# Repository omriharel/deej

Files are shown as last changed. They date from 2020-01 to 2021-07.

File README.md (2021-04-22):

# deej

deej is an **open-source hardware volume mixer** for Windows and Linux PCs. It lets you use real-life sliders (like a DJ!) to **seamlessly control the volumes of different apps** (such as your music player, the game you're playing and your voice chat session) without having to stop what you're doing.

**Join the [deej Discord server](https://discord.gg/nf88NJu) if you need help or have any questions!**



> **_New:_** [work-in-progress deej FAQ](./docs/faq/faq.md)!

deej consists of a [lightweight desktop client](#features) written in Go, and an Arduino-based hardware setup that's simple and cheap to build. [**Check out some versions built by members of our community!**](./community.md)

**[Download the latest release](https://github.com/omriharel/deej/releases/latest) | [Video demonstration](https://youtu.be/VoByJ4USMr8) | [Build video by Tech Always](https://youtu.be/x2yXbFiiAeI)**

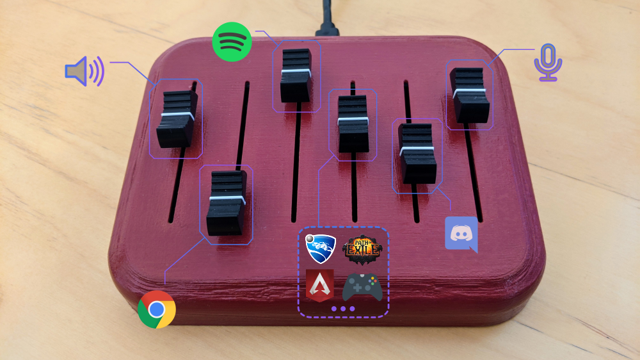
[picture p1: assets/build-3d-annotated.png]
deej


> _**Psst!** [No 3D printer? No problem!](./assets/build-shoebox.jpg)_ You can build deej on some cardboard, a shoebox or even a breadboard :)

## Table of contents

- [Features](#features)
- [How it works](#how-it-works)
  - [Hardware](#hardware)
    - [Schematic](#schematic)
  - [Software](#software)
- [Slider mapping (configuration)](#slider-mapping-configuration)
- [Build your own!](#build-your-own)
  - [FAQ](#faq)
  - [Build video](#build-video)
  - [Bill of Materials](#bill-of-materials)
  - [Thingiverse collection](#thingiverse-collection)
  - [Build procedure](#build-procedure)
- [How to run](#how-to-run)
  - [Requirements](#requirements)
  - [Download and installation](#download-and-installation)
  - [Building from source](#building-from-source)
- [Community](#community)
- [License](#license)

## Features

deej is written in Go and [distributed](https://github.com/omriharel/deej/releases/latest) as a portable (no installer needed) executable.

- Bind apps to different sliders
  - Bind multiple apps per slider (i.e. one slider for all your games)
  - Bind the master channel
  - Bind "system sounds" (on Windows)
  - Bind specific audio devices by name (on Windows)
  - Bind currently active app (on Windows)
  - Bind all other unassigned apps
- Control your microphone's input level
- Lightweight desktop client, consuming around 10MB of memory
- Runs from your system tray
- Helpful notifications to let you know if something isn't working

> **Looking for the older Python version?** It's no longer maintained, but you can always find it in the [`legacy-python` branch](https://github.com/omriharel/deej/tree/legacy-python).

## How it works

### Hardware

- The sliders are connected to 5 (or as many as you like) analog pins on an Arduino Nano/Uno board. They're powered from the board's 5V output (see schematic)
- The board connects via a USB cable to the PC

#### Schematic

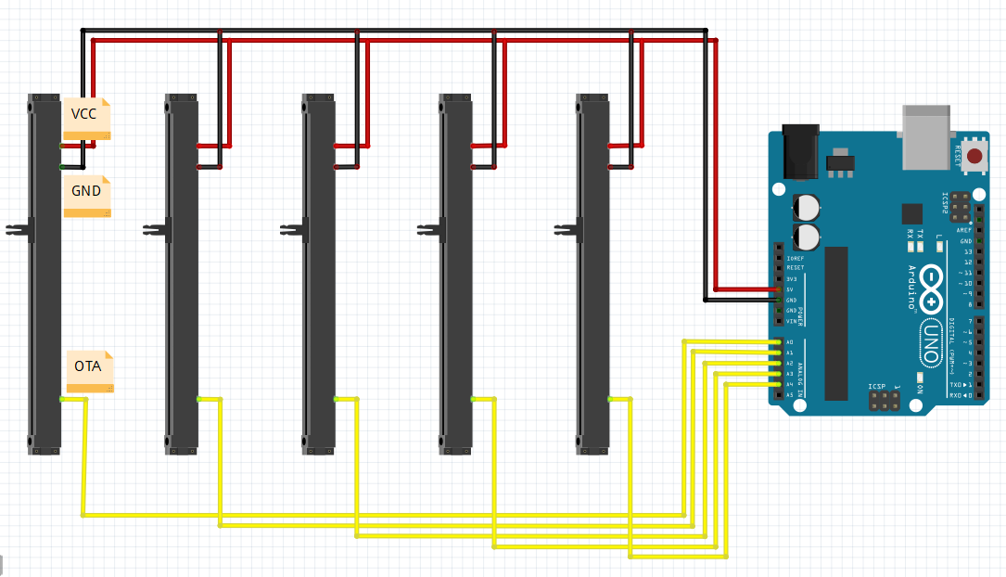
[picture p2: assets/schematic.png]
Hardware schematic


### Software

- The code running on the Arduino board is a [C program](./arduino/deej-5-sliders-vanilla/deej-5-sliders-vanilla.ino) constantly writing current slider values over its serial interface
- The PC runs a lightweight [Go client](./pkg/deej/cmd/main.go) in the background. This client reads the serial stream and adjusts app volumes according to the given configuration file

## Slider mapping (configuration)

deej uses a simple YAML-formatted configuration file named [`config.yaml`](./config.yaml), placed alongside the deej executable.

The config file determines which applications (and devices) are mapped to which sliders, and which parameters to use for the connection to the Arduino board, as well as other user preferences.

**This file auto-reloads when its contents are changed, so you can change application mappings on-the-fly without restarting deej.**

It looks like this:

```yaml
slider_mapping:
  0: master
  1: chrome.exe
  2: spotify.exe
  3:
    - pathofexile_x64.exe
    - rocketleague.exe
  4: discord.exe

# set this to true if you want the controls inverted (i.e. top is 0%, bottom is 100%)
invert_sliders: false

# settings for connecting to the arduino board
com_port: COM4
baud_rate: 9600

# adjust the amount of signal noise reduction depending on your hardware quality
# supported values are "low" (excellent hardware), "default" (regular hardware) or "high" (bad, noisy hardware)
noise_reduction: default
```

- `master` is a special option to control the master volume of the system _(uses the default playback device)_
- `mic` is a special option to control your microphone's input level _(uses the default recording device)_
- `deej.unmapped` is a special option to control all apps that aren't bound to any slider ("everything else")
- On Windows, `deej.current` is a special option to control whichever app is currently in focus
- On Windows, you can specify a device's full name, i.e. `Speakers (Realtek High Definition Audio)`, to bind that device's level to a slider. This doesn't conflict with the default `master` and `mic` options, and works for both input and output devices.
  - Be sure to use the full device name, as seen in the menu that comes up when left-clicking the speaker icon in the tray menu
- `system` is a special option on Windows to control the "System sounds" volume in the Windows mixer
- All names are case-**in**sensitive, meaning both `chrome.exe` and `CHROME.exe` will work
- You can create groups of process names (using a list) to either:
    - control more than one app with a single slider
    - choose whichever process in the group that's currently running (i.e. to have one slider control any game you're playing)

## Build your own!

Building deej is very simple. You only need a few relatively cheap parts - it's an excellent starter project (and my first Arduino project, personally). Remember that if you need any help or have a question that's not answered here, you can always [join the deej Discord server](https://discord.gg/nf88NJu).

Build deej for yourself, or as an awesome gift for your gaming buddies!

### FAQ

I've started a highly focused effort of writing a proper FAQ page for deej, covering many basic and advanced topics.

It is still _very much a work-in-progress_, but I'm happy to [share it in its current state](./docs/faq/faq.md) in hopes that it at least covers some questions you might have.

FAQ feedback in our [community Discord](https://discord.gg/nf88NJu) is strongly encouraged :)

### Build video

In case you prefer watching to reading, Charles from the [**Tech Always**](https://www.youtube.com/c/TechAlways) YouTube channel has made [**a fantastic video**](https://youtu.be/x2yXbFiiAeI) that covers the basics of building deej for yourself, including parts, costs, assembly and software. I highly recommend checking it out!

### Bill of Materials

- An Arduino Nano, Pro Micro or Uno board
  - I officially recommend using a Nano or a Pro Micro for their smaller form-factor, friendlier USB connectors and more analog pins. Plus they're cheaper
  - You can also use any other development board that has a Serial over USB interface
- A few slider potentiometers, up to your number of free analog pins (the cheaper ones cost around 1-2 USD each, and come with a standard 10K Ohm variable resistor. These _should_ work just fine for this project)
  - **Important:** make sure to get **linear** sliders, not logarithmic ones! Check the product description
  - You can also use circular knobs if you like
- Some wires
- Any kind of box to hold everything together. **You don't need a 3D printer for this project!** It works fantastically with just a piece of cardboard or a shoebox. That being said, if you do have one, read on...

### Thingiverse collection

With many different 3D-printed designs being added to our [community showcase](./community.md), it felt right to gather all of them in a Thingiverse collection for you to browse. If you have access to a 3D printer, feel free to use one of the designs in your build.

**[Visit our community-created design collection on Thingiverse!](https://thingiverse.com/omriharel/collections/deej)**

> You can also [submit your own](https://discord.gg/nf88NJu) design to be added to the collection. Regardless, if you do upload your design to Thingiverse, _please add a `deej` tag to it so that others can find it more easily_.

### Build procedure

- Connect everything according to the [schematic](#schematic)
- Test with a multimeter to be sure your sliders are hooked up correctly
- Flash the Arduino chip with the sketch in [`arduino\deej-5-sliders-vanilla`](./arduino/deej-5-sliders-vanilla/deej-5-sliders-vanilla.ino)
  - _Important:_ If you have more or less than 5 sliders, you must edit the sketch to match what you have
- After flashing, check the serial monitor. You should see a constant stream of values separated by a pipe (`|`) character, e.g. `0|240|1023|0|483`
  - When you move a slider, its corresponding value should move between 0 and 1023
- Congratulations, you're now ready to run the deej executable!

## How to run

### Requirements

#### Windows

- Windows. That's it

#### Linux

- Install `libgtk-3-dev`, `libappindicator3-dev` and `libwebkit2gtk-4.0-dev` for system tray support. Pre-built Linux binaries aren't currently released, so you'll need to [build from source](#building-from-source). If there's demand for pre-built binaries, please [let me know](https://discord.gg/nf88NJu)!

### Download and installation

- Head over to the [releases page](https://github.com/omriharel/deej/releases) and download the [latest version](https://github.com/omriharel/deej/releases/latest)'s executable and configuration file (`deej.exe` and `config.yaml`)
- Place them in the same directory anywhere on your machine
- (Optional, on Windows) Create a shortcut to `deej.exe` and copy it to `%APPDATA%\Microsoft\Windows\Start Menu\Programs\Startup` to have deej run on boot

### Building from source

If you'd rather not download a compiled executable, or want to extend deej or modify it to your needs, feel free to clone the repository and build it yourself. All you need is a Go 1.14 (or above) environment on your machine. If you go this route, make sure to check out the [developer scripts](./pkg/deej/scripts).

Like other Go packages, you can also use the `go get` tool: `go get -u github.com/omriharel/deej`. Please note that the package code now resides in the `pkg/deej` directory, and needs to be imported from there if used inside another project.

If you need any help with this, please [join our Discord server](https://discord.gg/nf88NJu).

## Community



deej is a relatively new project, but a vibrant and awesome community is rapidly growing around it. Come hang out with us in the [deej Discord server](https://discord.gg/nf88NJu), or check out a whole bunch of cool and creative builds made by our members in the [community showcase](./community.md).

The server is also a great place to ask questions, suggest features or report bugs (but of course, feel free to use GitHub if you prefer).

### Donations

If you love deej and want to show your support for this project, you can do so using the link below. Please don't feel obligated to donate - building the project and telling your friends about it goes a very long way! Thank you very much.



### Contributing

Please see [`docs/CONTRIBUTING.md`](./docs/CONTRIBUTING.md).

## License

deej is released under the [MIT license](./LICENSE).

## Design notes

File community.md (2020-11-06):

# Community showcase

This is a showcase of `deej` versions built by people around the world. Many of those who featured their builds here regularly hang around in [our Discord server](https://discord.gg/nf88NJu), so you can ask them any questions you might have.

We've also gathered many of the community-created 3D designs featured here in a [Thingiverse collection](https://thingiverse.com/omriharel/collections/deej) for your viewing pleasure. Feel free to use them for your own builds if you have access to a 3D printer.

If you built yourself one of these things, I'd love to [add yours](https://discord.gg/nf88NJu)!

## [/u/Aithorn](https://reddit.com/user/Aithorn)

**Links**: [Imgur album](https://imgur.com/a/Y1rKJmc) | [Reddit](https://redd.it/fc2l3x) | [Enclosure model on Thingiverse](https://www.thingiverse.com/thing:4196719) | [Featured on Arduino Blog!](https://blog.arduino.cc/2020/03/04/control-the-volume-of-programs-running-on-your-windows-pc-like-a-dj/) | [Alternate knobs](https://i.imgur.com/WjaA58d.jpg)

This build features a very neat 3D-printed enclosure to fit the sliders, and uses an Arduino Nano board.

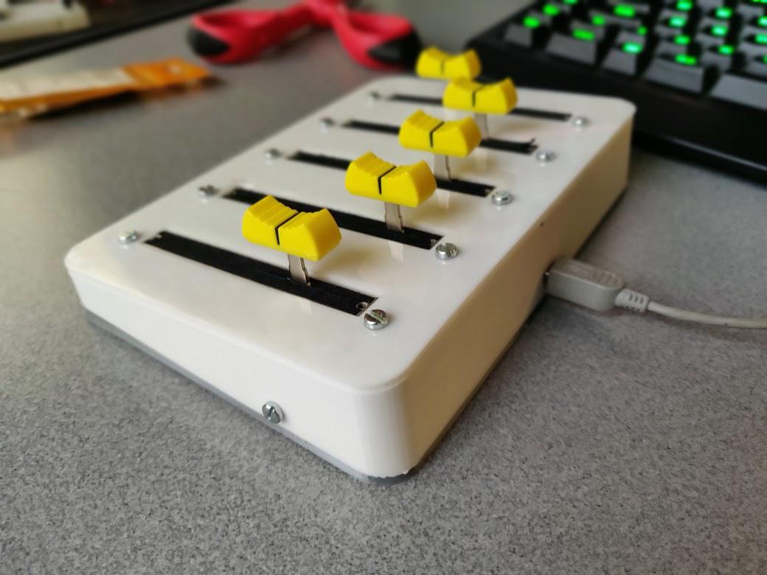
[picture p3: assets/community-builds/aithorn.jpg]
/u/Aithorn


## [Bupher](https://github.com/Bupher)

**Links**: [Imgur album](https://imgur.com/a/5uHYhxW) | [Enclosure model on Thingiverse](https://www.thingiverse.com/thing:4641048) | [GitHub fork](https://github.com/Bupher/deej) | [Video 1](https://youtu.be/O2UJv-sJEjA) | [Video 2](https://youtu.be/psEt-rckr8U)

This updated build uses circular knobs instead of sliders, and adds a 7-segment display showing the volume of the last adjusted knob. The five buttons are used to trigger various macros that the author configured separately. Most recently this build was augmented to include built-in support for Corsair's iCUE RGB control. This allows using Corsair's desktop software to control the lighting on this deej design similarly to an RGB keyboard. The required Arduino-side code modifications are available in Bupher's fork (link above). Very cool!

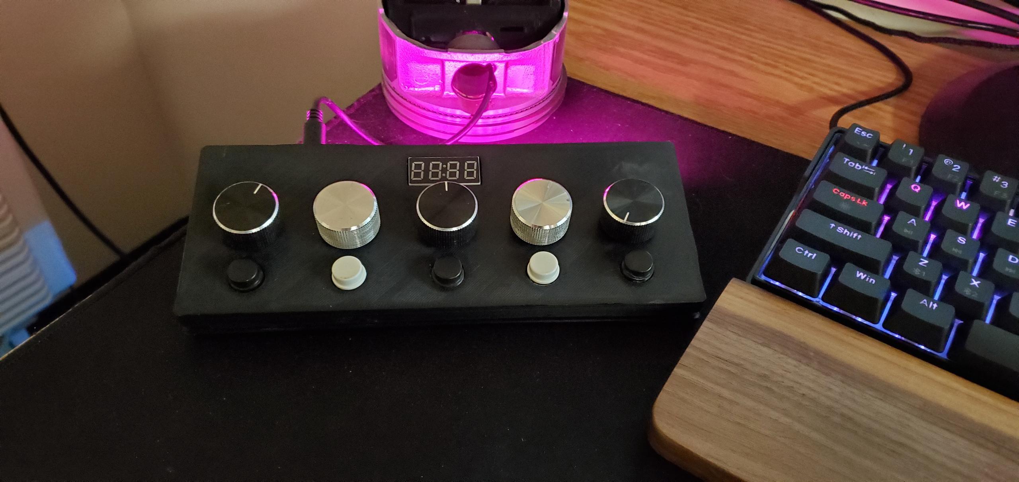
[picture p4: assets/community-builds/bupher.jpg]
Bupher


## Dimitar

**Links**: Schematic ([.png](./assets/community-builds/extra/dimitar-schematic.png) | [.sch](./assets/community-builds/extra/dimitar-schematic.sch))

This build, based on the above 3D-printed enclosure by [/u/Aithorn](#uaithorn), adds onto it with additional holes drilled for fading LEDs and mute toggles. Their wiring is detailed in the schematic that Dimitar has kindly provided (link above).. The sleek dark appearance, coupled with the differently colored knobs and LEDs, makes for a very professional look.

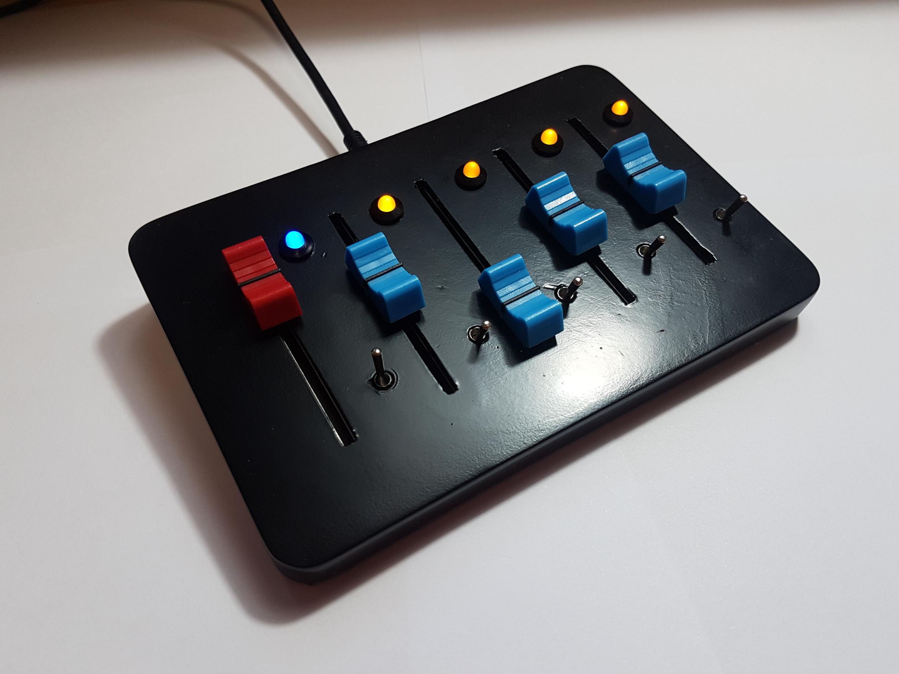
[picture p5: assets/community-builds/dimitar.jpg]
Dimitar


## [/u/jeremytodd1](https://reddit.com/user/jeremytodd1)

**Links**: [Imgur album](https://imgur.com/a/ys1RLwr)

This build is based on the above 3D-printed enclosure by [/u/Aithorn](#uaithorn) and also uses their 3D-printed knobs for its sliders.

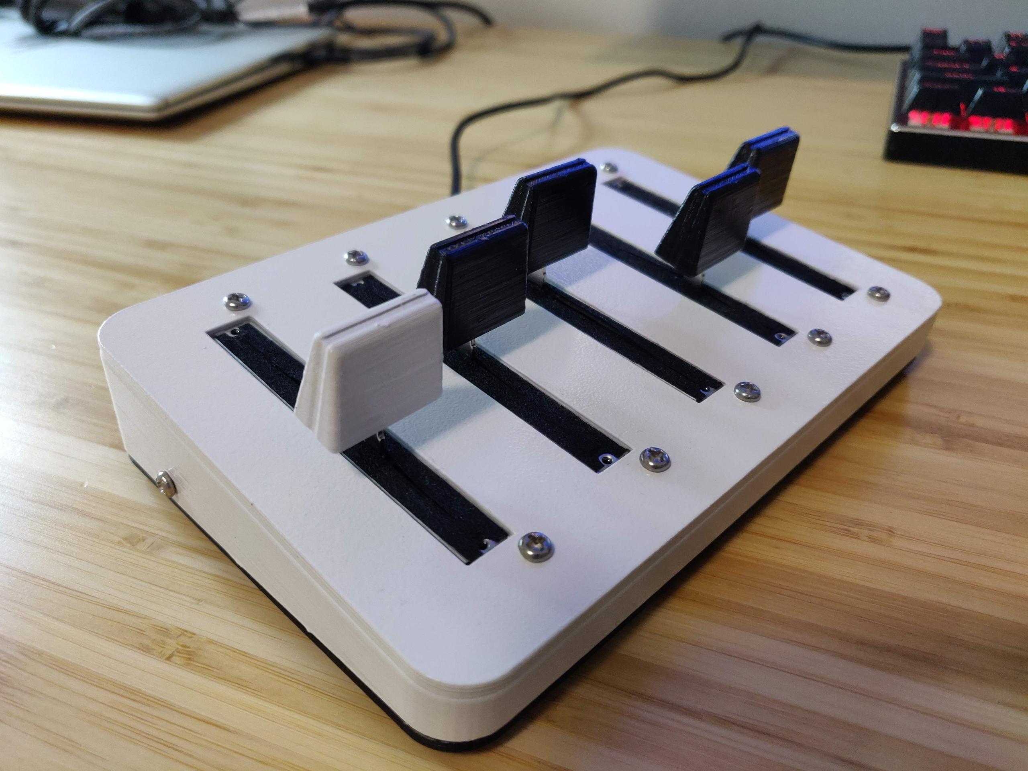
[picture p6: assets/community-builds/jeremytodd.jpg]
/u/jeremytodd1


## CptnObvious

**Links**: [Imgur album](https://imgur.com/a/pnptoo7)

This build uses a flat 3D-printed enclosure, but the real kicker is its magnetically-snapping application logo covers, made with a midway-filament-swapping technique. Looking snappy!

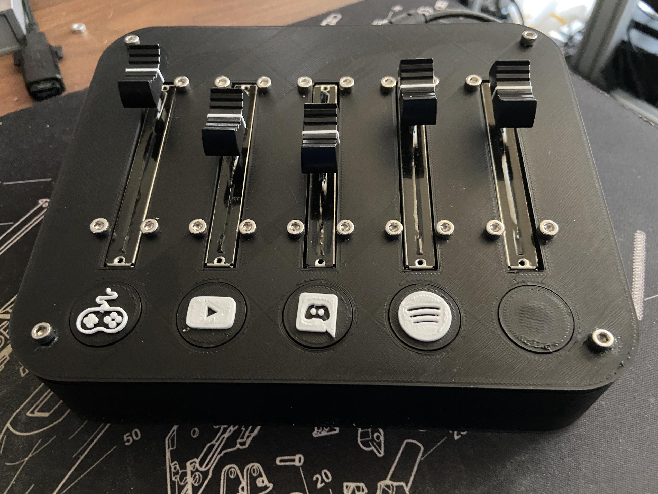
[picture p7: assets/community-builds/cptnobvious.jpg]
CptnObvious


## nightfox939

**Links**: [Imgur album](https://imgur.com/a/rrLbTHI) | [Enclosure model on Thingiverse](https://www.thingiverse.com/thing:4460296)

This build takes a different spin on 3D-printed enclosures by positioning the sliders at an angle, such that the box can be placed right behind the keyboard (as shown [here](https://i.imgur.com/FuvaaTO.jpg)). It also features seven sliders, which is fantastic for power users.

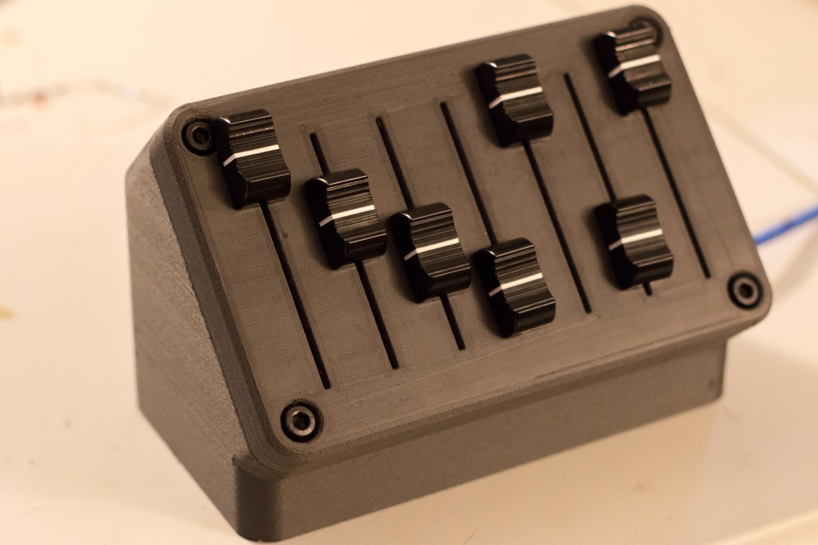
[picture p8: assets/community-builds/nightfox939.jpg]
nightfox939


## [Snackya](https://github.com/Snackya)

**Links**: [Imgur album](https://imgur.com/a/ZL6UBuR) | [GitHub repository with PCB files and instructions](https://github.com/Snackya/Snackboard-mix)

This one's a very special build, as it's designed to look great with absolutely no 3D printing, mill or any casing at all. It's made with custom PCBs that are mounted together with bolts and nuts. The top plate's silkscreen layer adds its own visual flair. The build uses six 100 mm sliders and an Arduino Pro Micro. Snackya has kindly provided the gerber files, as well as detailed instructions, in their GitHub repository (link above).

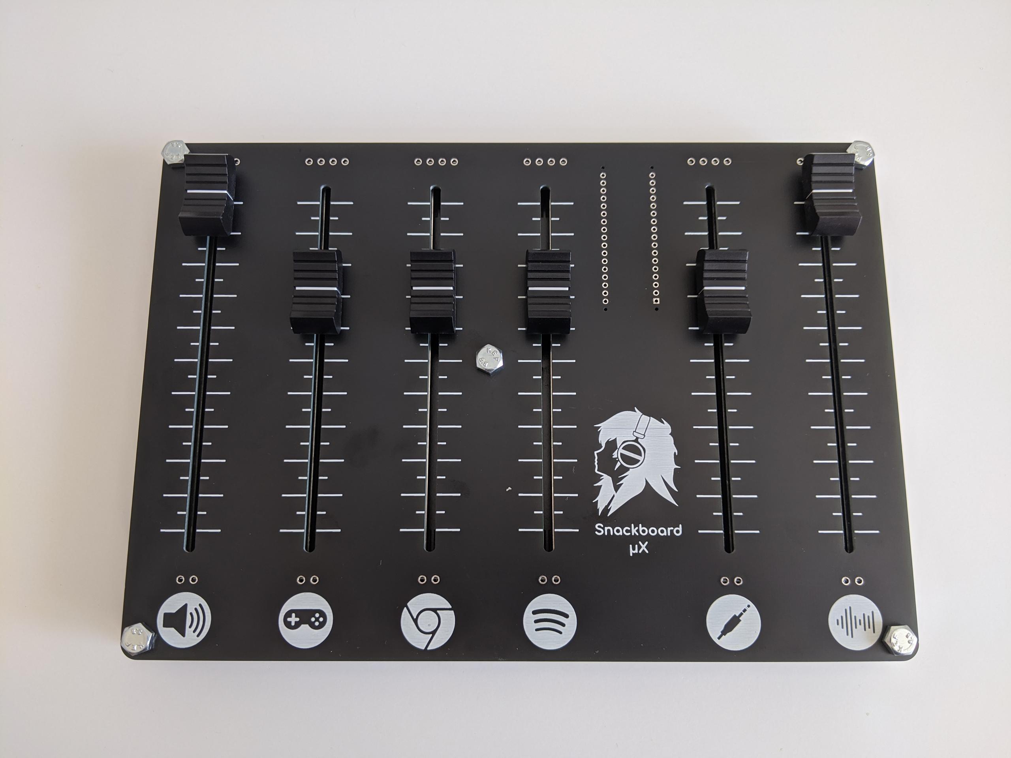
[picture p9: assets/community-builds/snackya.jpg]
Snackya


## [olijoe](https://github.com/olijoe)

**Links**: [Imgur album](https://imgur.com/a/Wibnqi7) | [GitHub repository with PCB files and instructions](https://github.com/olijoe/Deej-board)

This PCB build also takes advantage of sandwiching between two identical custom PCBs to avoid any need for 3D printing or other tools. Both sides of the PCB are used, one for mounting and wiring the components and the other for the silkscreen design (which in this case features some app logos and a cute geometric alpaca). olijoe has kindly provided the gerber files, as well as detailed insturctions, in their GitHub repository (link above).

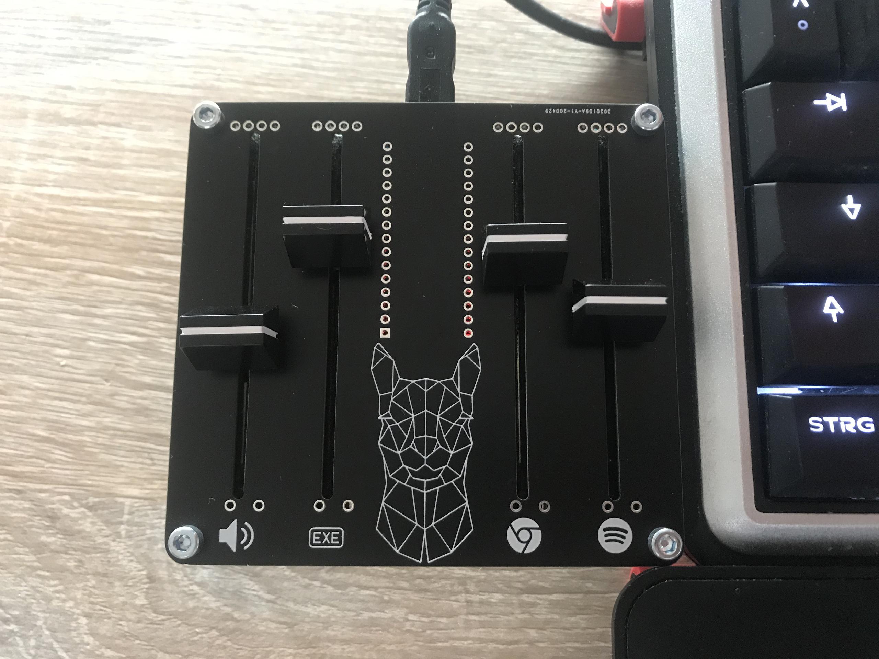
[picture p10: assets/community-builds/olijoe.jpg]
olijoe


## [Daggr](https://www.thingiverse.com/daggr)

**Links**: [Imgur album](https://imgur.com/a/YmTALay) | [Enclosure model on Thingiverse](https://www.thingiverse.com/thing:4555424) | [Blog post](https://blogg.spofify.se/index.php/2020/07/28/physical-volume-controller-part-2/)

This design is a remixed version of the above build by [nightfox939](#nightfox939), this time using five circular knobs instead of sliders. It adds onto it with a patterned top infill in the slicer settings, as well as some sharp looking filament-swapped app icons.

Daggr

## [/u/thesqueakywheel](https://reddit.com/user/thesqueakywheel)

**Links**: [Imgur album](https://imgur.com/a/vTsrSa7) | [Enclosure model on Thingiverse](https://www.thingiverse.com/thing:4557639)

This one's a compact 3-part design made to be [mounted to the underside of a desk](https://i.imgur.com/hGB5NH2.png). Each part is flat to allow for easy 3D printing without support material. The design is made such that the mounting plate in-between the two covers is actually what's holding them together and hidden between them for a seamless packaging.

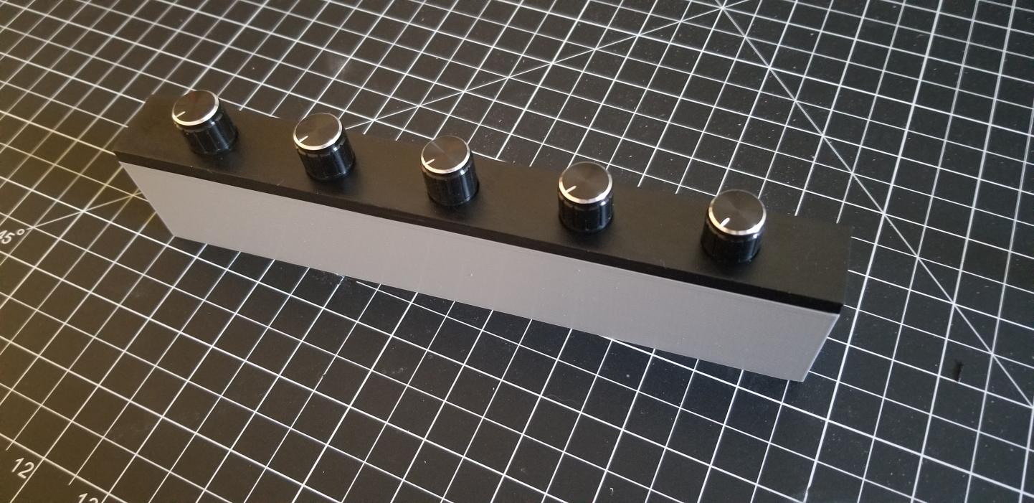
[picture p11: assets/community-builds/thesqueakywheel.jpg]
/u/thesqueakywheel


## [Optagon](https://www.thingiverse.com/Optagon)

**Links**: [Imgur album](https://imgur.com/a/8WKr8W9) | [Enclosure model on Thingiverse](https://www.thingiverse.com/thing:4556291)

This design incorporates fading LEDs that shine through 3D-printed app icons (they look way better in reality, but hopefully the picture gives a bit of an idea). Instructions for how to wire everything up, including some pictures, are inside the links above. A bright idea, and some very stylish execution!

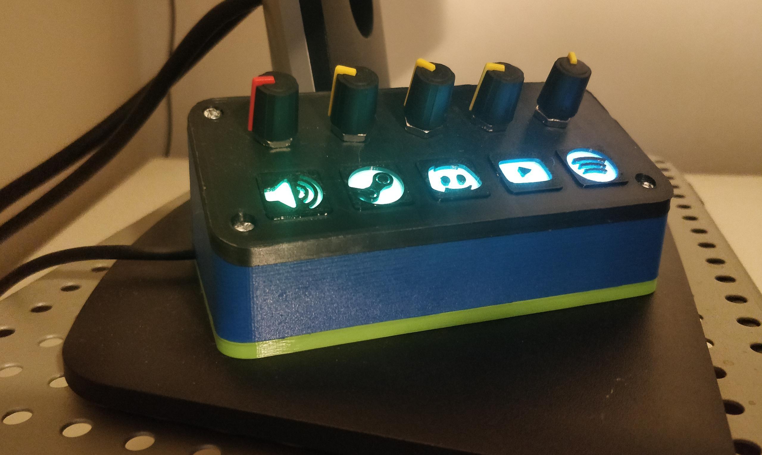
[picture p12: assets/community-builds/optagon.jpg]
Optagon


## mozza

**Links**: [Imgur album](https://imgur.com/a/suMAJ5Y) | [Enclosure model on Thingiverse](https://www.thingiverse.com/thing:4558424)

This compact build was designed to be positioned side-by-side with a keyboard. Contrary to most other designs, the knobs here are laid out vertically, making ideal use of the space they occupy. Perfect for a quick adjustment without ever taking off your hand from that side of the keyboard! Oh, and there's a similar version by the same author [below](#mozza-v2) if you're interested.

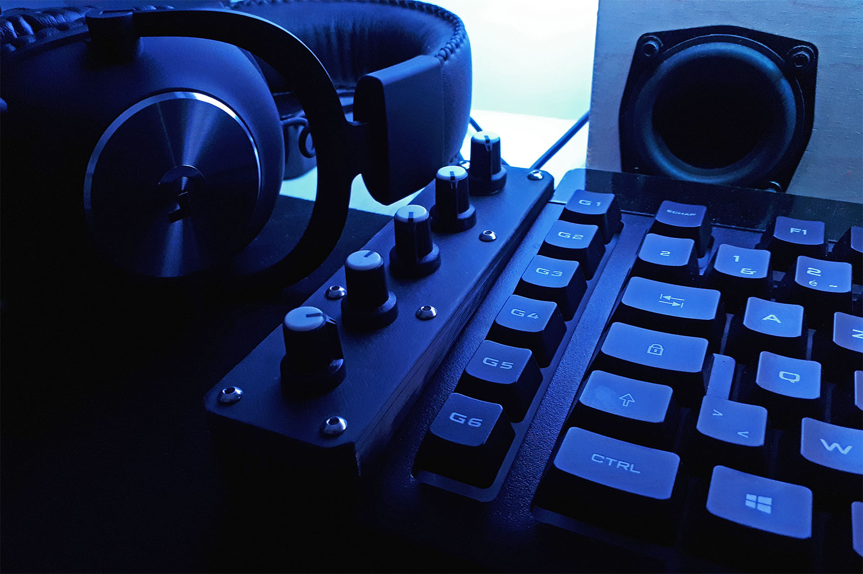
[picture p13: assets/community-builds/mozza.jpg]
mozza


## Max

**Links**: [Imgur album](https://imgur.com/a/T8OR4b3) | [Enclosure model on PrusaPrinters](https://www.prusaprinters.org/prints/37823-deej-mixer)

This build uses laser-cut acrylic as for its top plate which results in an absolutely stunning shine. It's lined with LEDs to indicate mute state, controllable by one of the two rows of buttons. The second row is used as custom triggers for F13-F19 keys, which brings a lot of added utility. This one's definitely for power users!

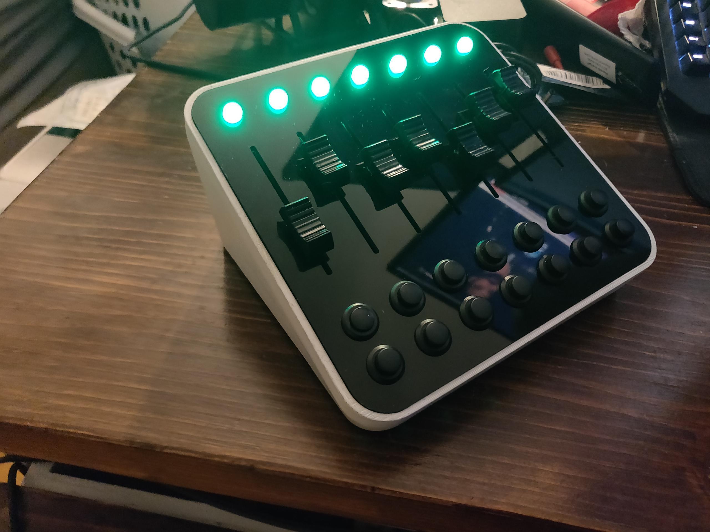
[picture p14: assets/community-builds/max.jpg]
Max


## [/u/functionalism](https://reddit.com/user/functionalism)

**Links**: [Imgur album](https://imgur.com/a/zavi9jL) | [Enclosure model on Thingiverse](https://www.thingiverse.com/thing:4561669)

This build uses a 3D-printed design remixed from [/u/Aithorn](#uaithorn)'s above enclosure. This one was made to be held in place by magnets, as it's situated on top of a metallic monitor stand. Magnets are also used instead of screws to hold the top cover and the enclosure's base together. In addition, app icons have been embossed into the 3D-printed slider knobs.

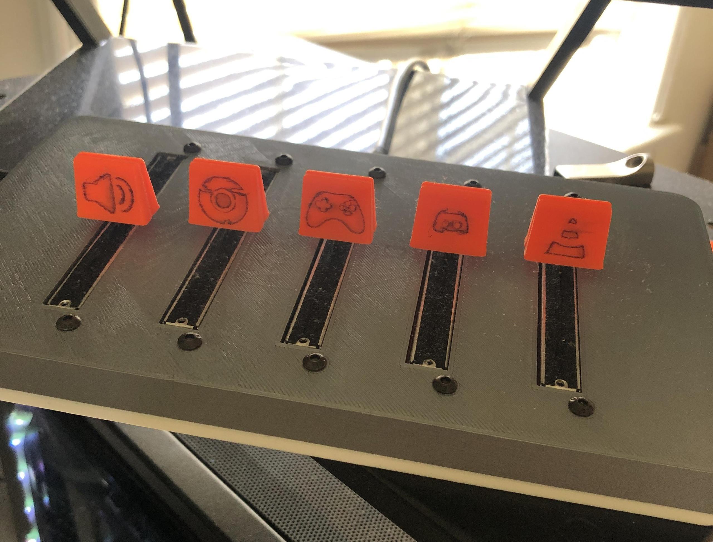
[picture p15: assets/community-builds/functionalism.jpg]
/u/functionalism


## [/u/Fantastic-Feature-84](https://reddit.com/user/Fantastic-Feature-84)

**Links**: [Imgur album](https://imgur.com/a/1q2MYI1) | [Enclosure model on Thingiverse](https://www.thingiverse.com/thing:4562009) | [Full Instructable](https://www.instructables.com/id/Hardware-Volume-Mixer-for-PC-With-RGB-LEDs)

This clever retro-style design features LEDs that change their color based on each slider's volume. These LEDs shine through light diffusers mounted below icon cutouts for the different apps, providing a controlled brightness that's easy on the eyes. In addition, a satisfying push button provides global mute toggling. /u/FantasticFeature84 has kindly provided full instructions for anyone else who wishes to build the same box, available on Instructables (link above).

/u/Fantastic-Feature-84

## [Cole Morris](http://colemorris.me)

**Links**: [Imgur album](https://imgur.com/a/qkSlVGt)

This compact 3D-printed build makes clever use of vertical space by having slight dips along each slider's travel area, making the knobs seem more integrated with the rest of the enclosure. The bright colors used for its different parts compliment each other well, and band together with its form factor and rounded edges to create a cute, toy-like appearance.

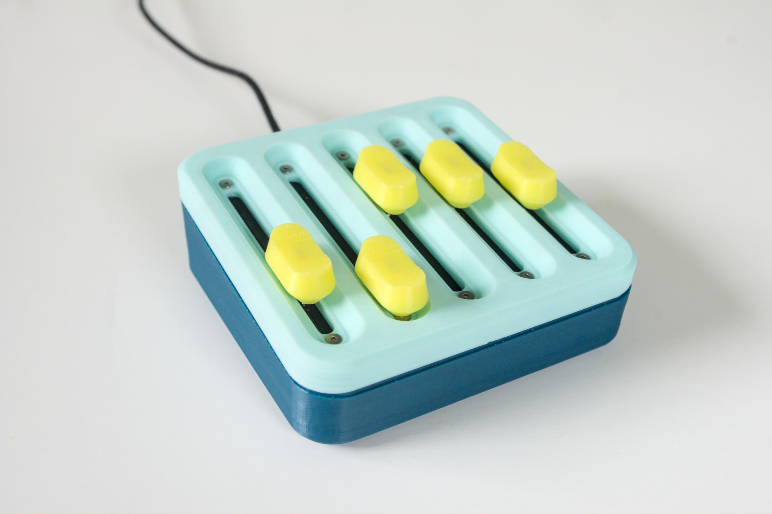
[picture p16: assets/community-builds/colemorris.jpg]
Cole Morris


## [wshaf](https://www.twitch.tv/wshaf)

**Links**: [Imgur album](https://imgur.com/a/KWONZ5A) | [Build VOD on Twitch](https://www.twitch.tv/videos/704168677)

This is a pink-and-black rendition of [/u/Aithorn](#uaithorn)'s above build, built by the author for one of their friends. Its primary use will be to control different audio sources while live-streaming on Twitch, which highlights deej's usefulness as a cheap DIY alternative to GoXLR and other similar products.

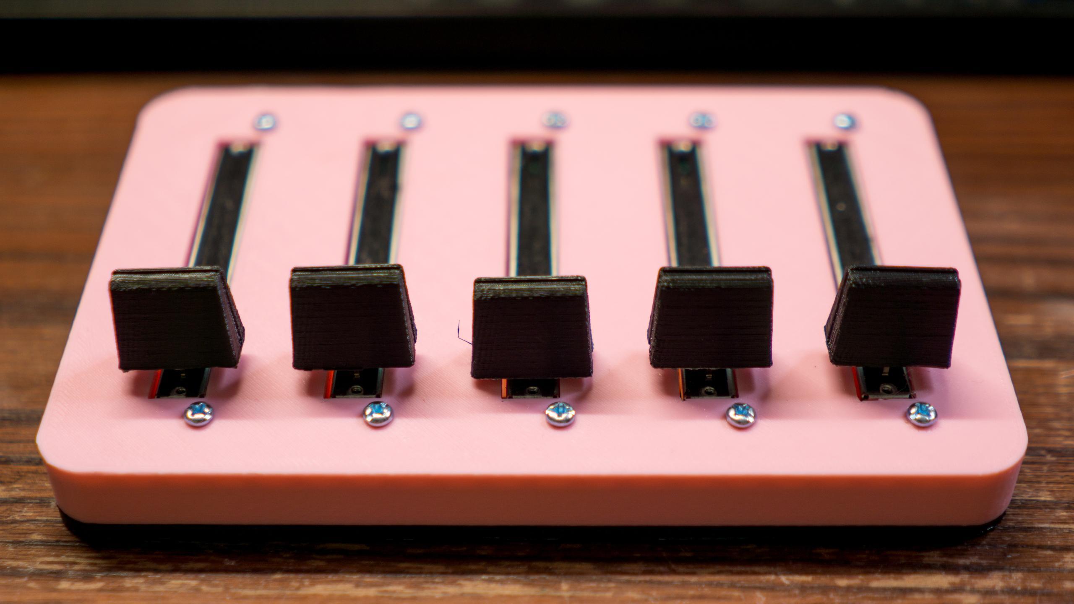
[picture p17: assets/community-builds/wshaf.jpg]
wshaf


## scotte

**Links**: [Imgur album](https://imgur.com/a/Wj2Fe5w) | [Enclosure model on Thingiverse](https://www.thingiverse.com/thing:4567647)

This one is a super-compact mini design! It features a 2-part snap-fit 3D-printed case, as well as 3D-printed knobs. With a total of three sliders and a tiny footprint of about 45 by 75 millimeters, this mini deej version is perfect for those looking to balance fewer audio sources and save some precious desk space. Did we mention it's adorable?

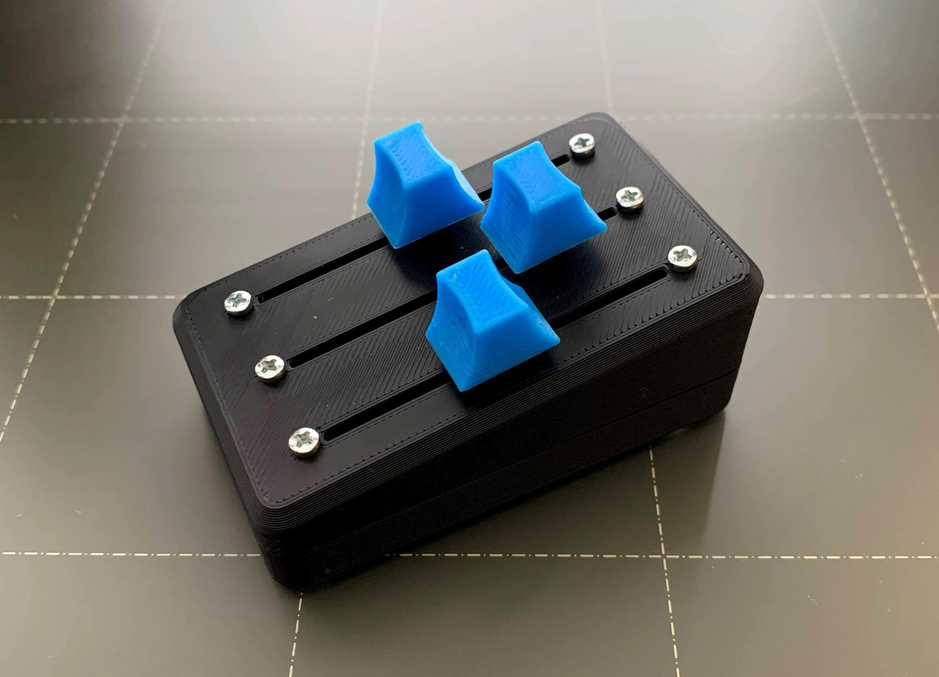
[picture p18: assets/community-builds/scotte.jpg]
scotte


## [Ginjah](https://www.twitch.tv/ginjah_)

**Links**: [Enclosure model on Thingiverse](https://www.thingiverse.com/thing:4569860)

This slanted, 3D-printed design consists of six potentiometers - five of them are sliders, and a large knob is used as a master volume control. It features buttons with built-in LEDs to indicate mute toggle state, with one button acting specifically as a global mute (which is the equivalent of turning down all sliders to zero) - this accomplishes muting applications across several audio devices as opposed to just `master` which uses the default. Also worth mentioning that the knob and slider caps are all 3D-printed too!

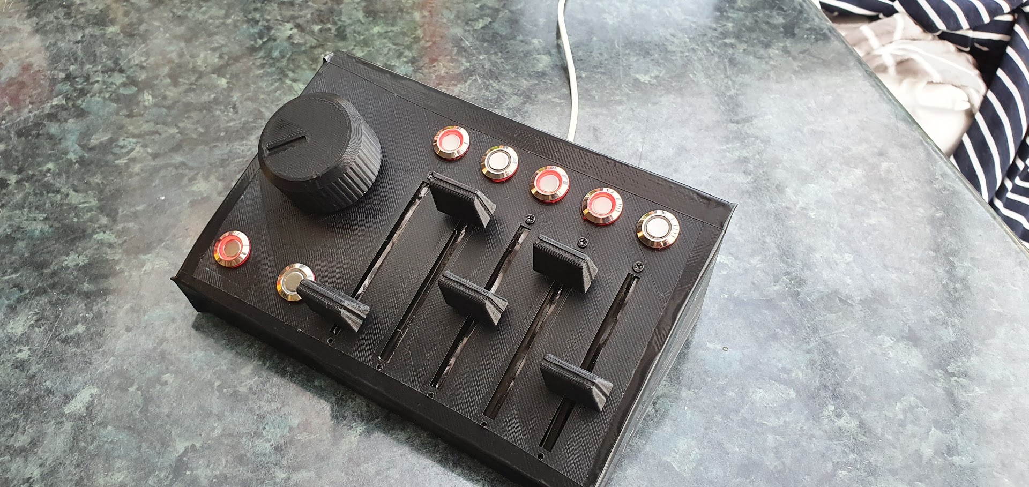
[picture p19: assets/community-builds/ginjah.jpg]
Ginjah


## mozza (v2)

**Links**: [Enclosure model on Thingiverse](https://www.thingiverse.com/thing:4570471)

This build is a follow up to the earlier version made by mozza ([showcased above](#mozza)). It features a combination of four sliders and one master volume knob. It was designed to match the same angle as the keyboard that's next to it. In addition to that, many rounds of sanding and filling have resulted in a professional surface finish that looks like an actual product.

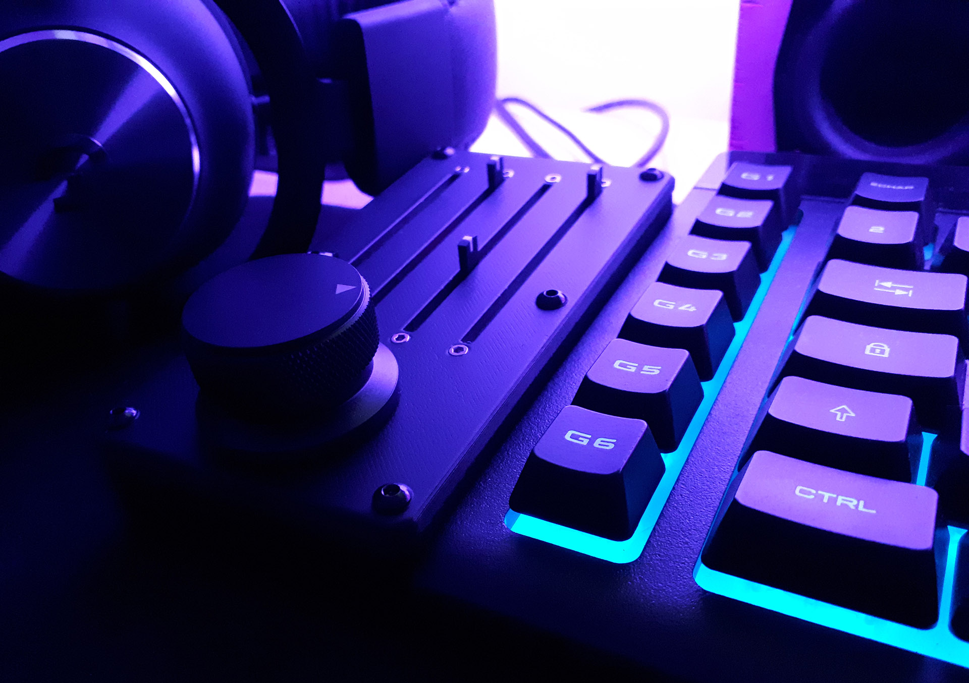
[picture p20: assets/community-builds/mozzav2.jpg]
mozza (v2)


## Probird

This simple build consists of five knobs with, wait for it - **2D**-printed app icons attached to its top surface (yes, it's a piece of paper and some glue). This is a good example for a design that users who are brand new to 3D-printing and CAD can make entirely from scratch.

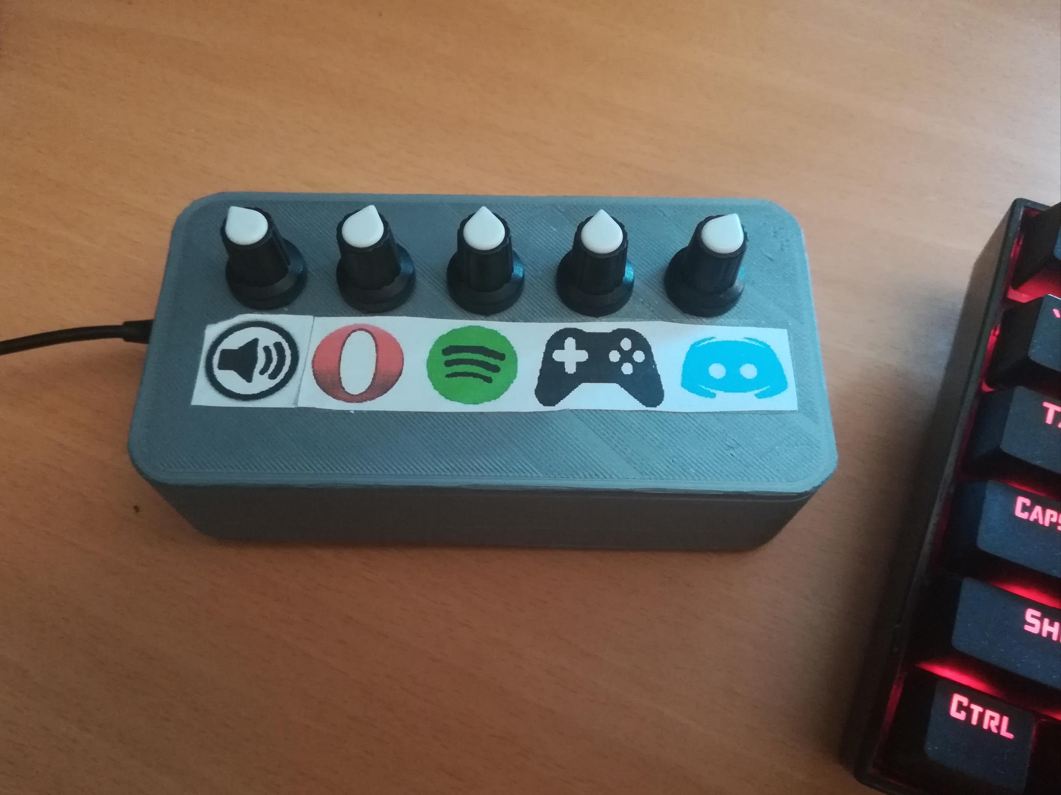
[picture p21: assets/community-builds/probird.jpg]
Probird


## [/u/DruciferRedBeard](https://reddit.com/user/DruciferRedBeard)

**Links**: [Imgur album](https://imgur.com/a/nBGLd9b) | [Enclosure model on Thingiverse](https://www.thingiverse.com/thing:4568300)

This wonderfully colorful build was made [twice](https://i.imgur.com/v3FQXkF.jpg) by its author, one for themselves and one for their son.  It's a clever 3D-printed design featuring no visible screws on its top surface, achieved by mounting a stabilizer in-between the top and bottom covers. The knobs have also been printed out with a satisfying range of colors (meant to represent different apps). The indicator line down the middle of each slider is made using the "color change" feature in PrusaSlicer. Elegant _and_ cheerful!

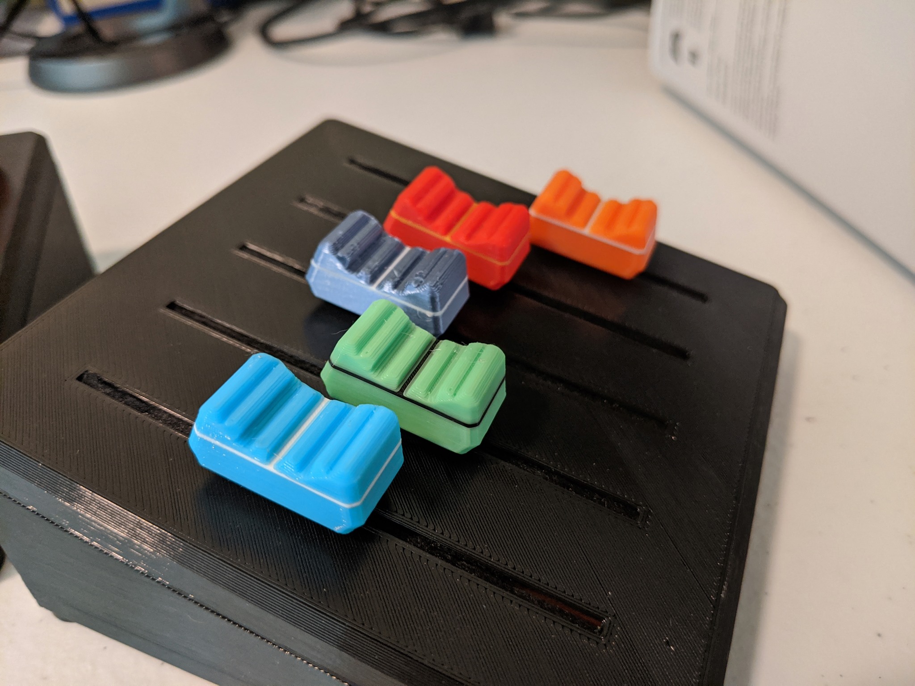
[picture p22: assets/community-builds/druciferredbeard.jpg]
/u/DruciferRedBeard


## Snaglebagle

**Links**: [Imgur album](https://imgur.com/a/QN7gyjP) | [Enclosure model on Thingiverse](https://www.thingiverse.com/thing:4579910)

This bright, red and black design has a neat retro look to it that's further complemented by its sharp corners. It has five sliders and uses the 3D-printed knobs designed by [/u/Aithorn](#uaithorn).

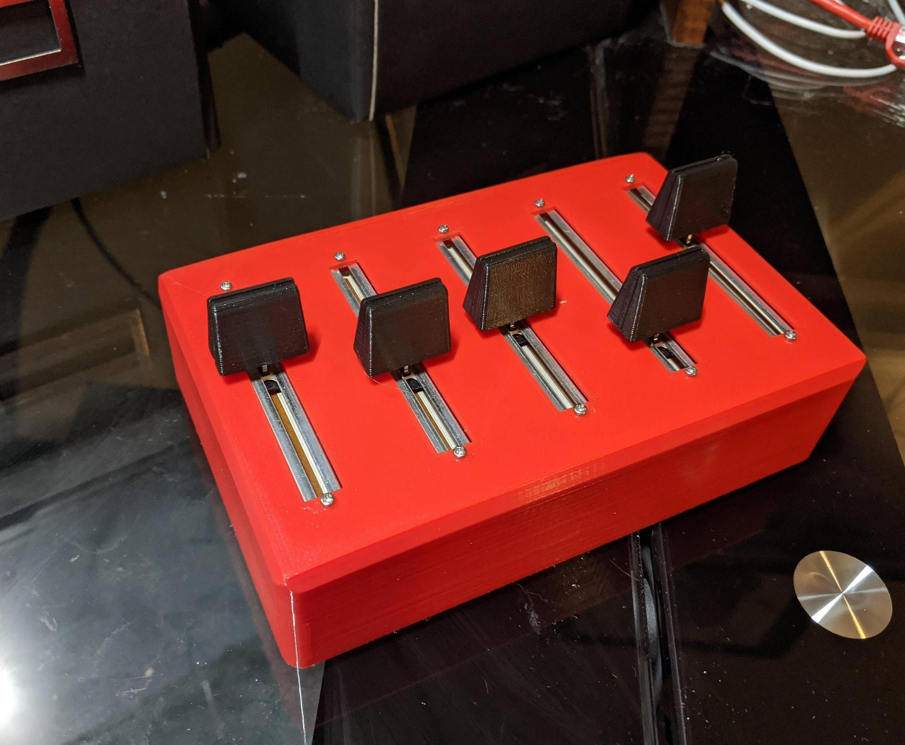
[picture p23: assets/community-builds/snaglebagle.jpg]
Snaglebagle


## [/u/Kawaru86](https://reddit.com/user/Kawaru86)

**Links**: [Imgur album](https://imgur.com/a/q2fENDF)

This unique build is based entirely on a breadboard! Two, to be exact. The author took some great pictures that [show the wiring](https://i.imgur.com/hUHCKup.jpg) for the project in a very clear (and quite satisfying) way. This is a fantastic, [stylish](https://i.imgur.com/2ETrBIE.jpg) choice for people without access to a 3D printer, or those looking for a way to build deej without soldering anything.

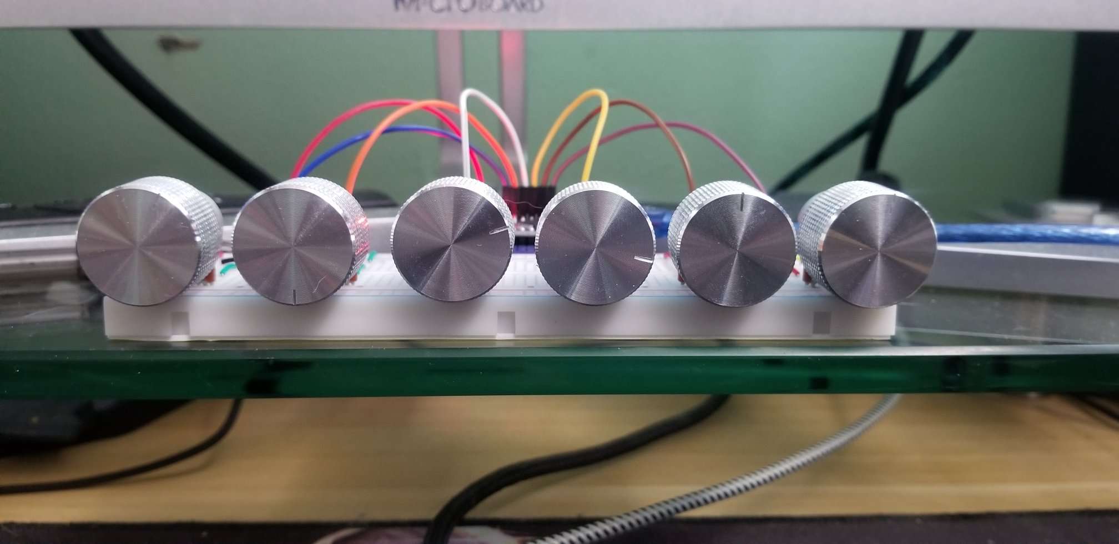
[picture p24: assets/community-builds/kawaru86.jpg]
/u/Kawaru86


## [/u/HumidLettuce](https://reddit.com/user/HumidLettuce)

**Links**: [Imgur album](https://imgur.com/a/AEpAJYi) | [Enclosure model on Thingiverse](https://www.thingiverse.com/thing:4580787) | [Full Instructable](https://www.instructables.com/id/Deej-Box-5-Sliders/)

This 3D-printed design has a smooth surface finish and features no front-facing screws. It uses magnetic, swappable plates with app icons below each slider, allowing you to easily tell which slider controls which app. In addition, the steep angle of this build lets it occupy slightly less desk space than other, more traditional slider-based designs. /u/HumidLettuce has kindly provided full, step-by-step build instructions for other users wishing to use this design, available on Instructables (link above).

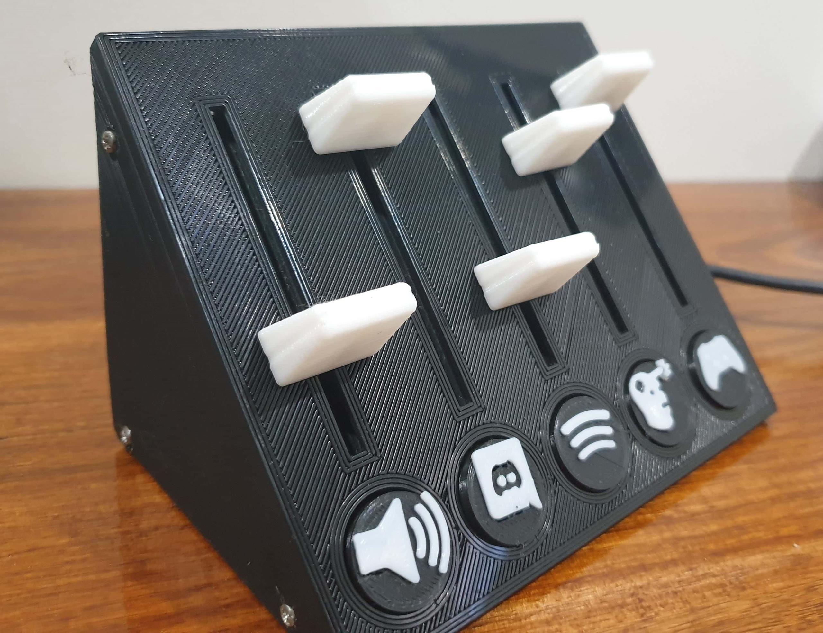
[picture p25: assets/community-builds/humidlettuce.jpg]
/u/HumidLettuce


## [Snow](https://reddit.com/user/NoU_14)

**Links**: [Imgur album](https://imgur.com/a/3XYqhJk)

This compact design uses a single rotary encoder (with a modified version of deej's Arduino code) that acts as several "virtual" knobs. Clicking the encoder toggles the control between them, with the active channel (and current volume level) being indicated by the OLED screen. It also incorporates an LED ring to act as a secondary volume level indicator, adding some visual flair to the build. The 3D-printed enclosure wraps everything up with a professional look, that (unintentionally!) somewhat resembles a classic iPod. The bottom side of the enclosure is filled with some plaster, giving it additional weight and allowing it to remain sturdy despite its small (8x4.5x2.3 cm) size.

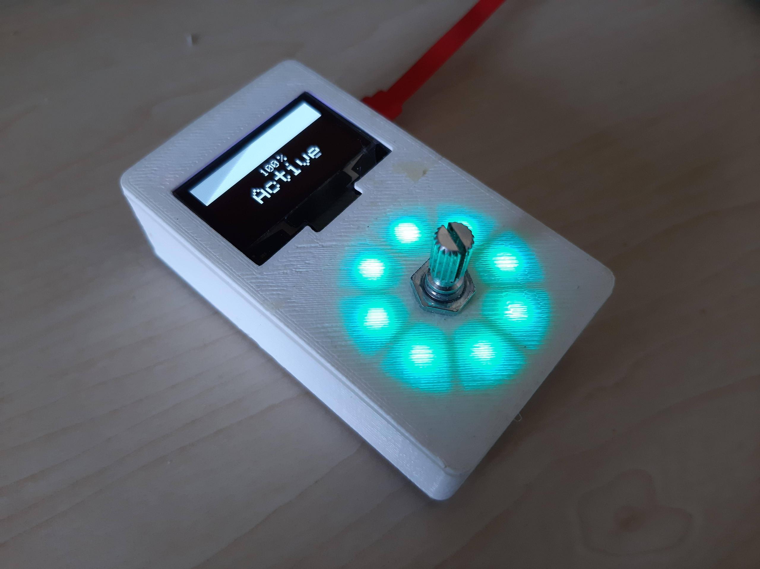
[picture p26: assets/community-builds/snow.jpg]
Snow


## YaMoef

**Links**: [Imgur album](https://imgur.com/a/3zxhjxF) | [Modified code on GitHub](https://github.com/YaMoef/deej)

This build presents a second, angled variation on the single rotary encoder approach, using a single component to control multiple "virtual sliders". It uses a heavily modified version of both Arduino code and the deej client (both of which the author has kindly made available in their GitHub fork, alongside detailed instructions - link above). It features an LCD display to indicate the active channel as well as the current volume level. Its 3D-printed exterior is finished off with a shiny, metallic volume knob to wrap up its sleek appearance.

YaMoef

## StalkyMuffin

**Links**: [Imgur album](https://imgur.com/a/zmfc3ft) | [Enclosure model on Thingiverse](https://www.thingiverse.com/thing:4595058)

This one is a traditional-looking slider-based build with some unique properties. It was designed with multi-material capabilities in mind, most notably apparent by the laser-cut wooden app glued to the top. These provide an interesting contrast to the multi-layered faceplate, printed with two different filaments to give the sliders their own highlight. It's also the first deej build to include a [cord strain relief](https://i.imgur.com/lK6twPm.jpg) instead of a USB port, which adds to its highly professional look and feel.

StalkyMuffin

## [ocyrus99](https://www.thingiverse.com/ocyrus99)

**Links**: [Imgur album](https://imgur.com/a/g5X6OSw) | [Enclosure model on Thingiverse](https://www.thingiverse.com/thing:4599505)

This build blends together a few different features to achieve a uniquely colorful look. It is remixed from the above build by [Optagon](#optagon) but has a lower profile. The app icons have been redesigned to include a thin 3D-printed base which acts as a light diffuser for LEDs mounted beneath each icon. These RGB LEDs are then controlled by the Arduino to transition their color as their corresponding knob is rotated. Finally, the round aluminum knobs provide a nice contrast to the plastic body, while also emitting some of the glow from the colored LEDs. If you're interested, ocyrus99 has kindly made their code available in the design's Thingiverse entry (link above). Great execution!

ocyrus99

## bgrier

**Links**: [Imgur album](https://imgur.com/a/2LFaeVV) | [Full Instructable](https://www.instructables.com/Arduino-Keyboard-Joystick-Extender-Box-and-Sound-C/)

This particularly special build will appeal to those who love analog controls (so everyone, yes?). It is a hybrid of deej together with a fully functional joystick controller! The creator is using it as a keyboard extender that can control certain interface elements, or certain things in games and simulators - but really, sky's the limit. The 3D-printed body has been designed and fabricated to match the color aesthetic of the creator's keyboard, and looks like a natural extension of its frame. As a bonus, bgrier has prepared a fully detailed Instructable for any of you who want to follow along and build it (link above). Oh, and even if you don't need a joystick, the fidget value is just incredible!

bgrier

## marcioasf

**Links**: [Imgur album](https://imgur.com/a/J6UNBDB)

This design is based on the above build by [Optagon](#optagon). The author chose to use 3D-printed knobs, and also printed the bottom part of the case with a translucent filament which lets the LED inside add a pleasant, diffused glow to its exterior.

marcioasf

## Bao

**Links**: [Imgur album](https://imgur.com/a/hrw3TvZ)

This incredibly creative design brings deej to life on a tiny Mentos can. Novelties aside, this build ends up with a very compact footprint and can be a fantastic idea for anyone without access to a 3D printer. Looks tough to wire up, but if you're building with a Mentos can you _clearly_ know what you're doing.

Bao

## AbbyTheGryphon

**Links**: [Imgur album](https://imgur.com/a/USUAesF) | [Enclosure model on MyMiniFactory](https://www.myminifactory.com/object/3d-print-139957)

This design incorporates an amp-style appearance with a personalized touch. The five rotary potentiometers use plastic dials with a shiny metallic top, which adds a lot to that look. Additionally, tiny markings underneath each knob indicate the travel range for the pot. Crank it up to 11 with this one!

AbbyTheGryphon

## T-po

**Links**: [Imgur album](https://imgur.com/a/OuYZDQk)

This elegant build achieves its polished, professional look by using a project case to mount its top-facing components. It uses five identical rotary potentiometers, with the shiny aluminum knobs differentiating between the master knob and the other channels. It also features a mini USB to micro USB adapter (which makes up for the Nano's most glaring downside). The creator included some descriptions and part names in their Imgur album (link above).

T-po

## [Imagine Fabrication Lab](https://www.instagram.com/imaginefabricationlab/)

**Links**: [Imgur album](https://imgur.com/a/o8nZHDc) | [Enclosure model on Thingiverse](https://www.thingiverse.com/thing:4639592)

This design was made with power users in mind, incorporating no less than 12 buttons to trigger custom functionality with the Arduino Pro Micro's keyboard emulation capabilities (this requires a modified deej firmware). The 3D-printed buttons are mounted with a press fit, and can be swapped out as desired. Finally, these 45mm sliders offer a good amount of precision without taking up much space, resulting in a build that's fairly compact for the amount of firepower it packs.

Imagine Fabrication Lab

## [omnisai](https://relivesight.com/)

**Links**: [Imgur album](https://imgur.com/a/Z5luqwl) | [Blog entry!](https://relivesight.com/projects/encoder/) | [One more build by the author](https://relivesight.com/projects/deejx2/)

Another entry in the list of power-user oriented builds, this one-of-a-kind design was made from the case of a Behringer audio interface that its owner was willing to sacrifice. They added a fresh coat of paint, replaced the original components and made it into a thing of beauty. This build features no less than 9 potentiometers and 18 buttons, taking full advantage of everything the Arduino Pro Micro has to offer. The creator wrote a highly detailed blog post about the process on their website, I recommend giving it a read (link above)!

omnisai

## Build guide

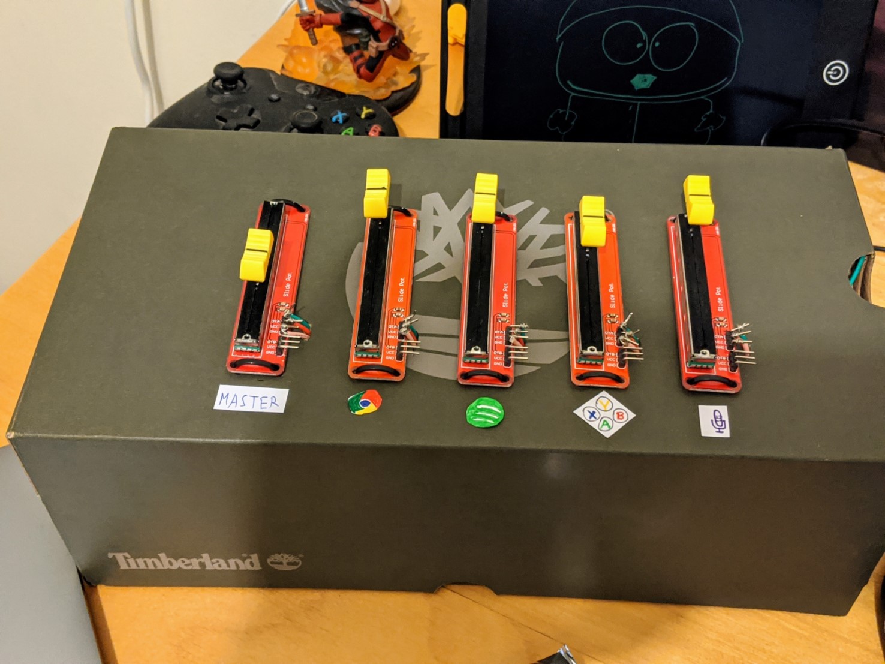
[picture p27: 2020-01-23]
assets/build-shoebox.jpg

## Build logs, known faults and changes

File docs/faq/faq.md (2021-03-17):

# deej FAQ

This document tries to cover all of the most commonly asked questions in our [community Discord server](https://discord.gg/nf88NJu), as well as provide basic troubleshooting for frequently-encountered problems by new deej users.

## Important - this is a **work-in-progress**!

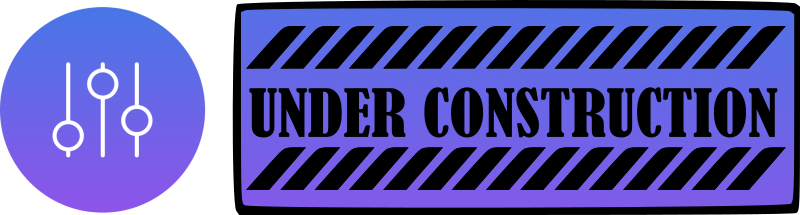
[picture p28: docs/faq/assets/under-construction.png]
Work in progress


**Please be aware that the current version of this FAQ is still _extremely_ work-in-progress.** It is released publicly in hopes that the questions already answered can be useful to some.

**All questions that have a complete answer have been marked with a "✔" in the table of contents, for your convenience.**

> Please also be aware that I am currently _not accepting_ GitHub contributions in the form of fully submitted answers to the unanswered questions below. You are welcome to submit them (alongside any other feedback) on our community Discord, however!

## Table of Contents

Use the following list of questions to quickly jump to what you're looking for.

> Can't find what you're looking for? Try searching for terms with a hashtag, such as _**#rotaryencoders**_. These are located near each question for easier finding of alternative keywords.

[**Electronics and hardware**](#electronics-and-hardware)

- **Parts & components**
  - [Which board should I get?](#which-board-should-i-get)
  - [What is the difference between sliders and knobs?](#what-is-the-difference-between-sliders-and-knobs) ✔
  - [Does the resistance of my pots matter? Do they need to be 10K?](#does-the-resistance-of-my-pots-matter-do-they-need-to-be-10k) ✔
  - [What are rotary encoders and can I use them instead of pots?](#what-are-rotary-encoders-and-can-i-use-them-instead-of-pots?)
- **Wiring**
  - [How should I **physically** wire my pots together?](#how-should-i-physically-wire-my-pots-together)
  - [How should I **logically/electronically** wire my pots together?](#how-should-i-logicallyelectronically-wire-my-pots-together) ✔
  - [How can I tell which pin is which on my sliders?](#how-can-i-tell-which-pin-is-which-on-my-sliders)
- **Extra hardware features**
  - [How do I add mute switches/toggles for each pot?](#how-do-i-add-mute-switchestoggles-for-each-pot)
  - [How do I add LED indicators?](#how-do-i-add-led-indicators)
  - [How do I add custom macro buttons?](#how-do-i-add-custom-macro-buttons)
  - [How do I add a toggle between output devices?](#how-do-i-add-a-toggle-between-output-devices)

[**Arduino**](#arduino)

- [I haven't used Arduino before, where to start?](#i-havent-used-arduino-before-where-to-start) ✔
- [How can I find my COM/serial port?](#how-can-i-find-my-comserial-port) ✔
- [How can I upload the deej sketch to my board?](#how-can-i-upload-the-deej-sketch-to-my-board) ✔
- [How do I know that I uploaded the deej sketch correctly?](#how-do-i-know-that-i-uploaded-the-deej-sketch-correctly) ✔
- I'm unable to connect to my board in the Arduino IDE...
  - [...for the first time ever](#for-the-first-time-ever) ✔
  - [...after connecting successfully in the past](#after-connecting-successfully-in-the-past) ✔
- [How do I view the serial monitor?](#how-do-i-view-the-serial-monitor) ✔

[**Running deej for the first time**](#running-deej-for-the-first-time)

- [What should I check before running deej.exe?](#)
- [I ran deej.exe but nothing happened](#)
- I ran deej.exe and got an error message...
  - [...about the config.yaml file](#)
  - [...about failed connection](#)
- [I turn my pots but nothing happens](#)
- [I ran deej.exe and my volume keeps jumping around](#)
- [My pots only seem to go up to around half volume](#)
- [All of my pots are inverted!](#all-of-my-pots-are-inverted) ✔
- [One of my pots is inverted](#one-of-my-pots-is-inverted) ✔

[**Editing the config file (config.yaml)**](#editing-the-config-file-configyaml)

- [How do I open and edit the config.yaml file?](#how-do-i-open-and-edit-the-configyaml-file) ✔
- [How can I check my config.yaml for errors?](#how-can-i-check-my-configyaml-for-errors) ✔
- [How do I add an app to the config.yaml file?](#how-do-i-add-an-app-to-the-configyaml-file) ✔
- [How can I find the .exe name of `insert app here`?](#how-can-i-find-the-exe-name-of-insert-app-here) ✔

[**Everyday deej usage**](#everyday-deej-usage)

- [Is there a way to make the volume go up/down by less than 3%?](#)
- [Can I put all my games on one slider without needing to add them one-by-one?](#can-i-put-all-my-games-on-one-slider-without-needing-to-add-them-one-by-one) ✔
- [The edges of my slider aren't as responsive as the middle](#)
- [How can I make deej start automatically when my PC boots?](#)
- [After my computer wakes up from sleep/hibernation deej doesn't work anymore](#)
- [Sometimes deej randomly stops working (without sleep/hibernation)](#)

[**Component housings and enclosures**](#component-housings-and-enclosures)

- [I don't have a 3D printer, can I still make this project?](#)
- [I have a 3D printer - where can I find a design to print?](#)

[**[↑]**](#deej-faq)

## Electronics and hardware

### What is the difference between sliders and knobs?

As long as you're referring to pots - nothing. The only difference is that one of them rotates while the other slides. Electrically, they work exactly the same and they're purely up to personal preference.

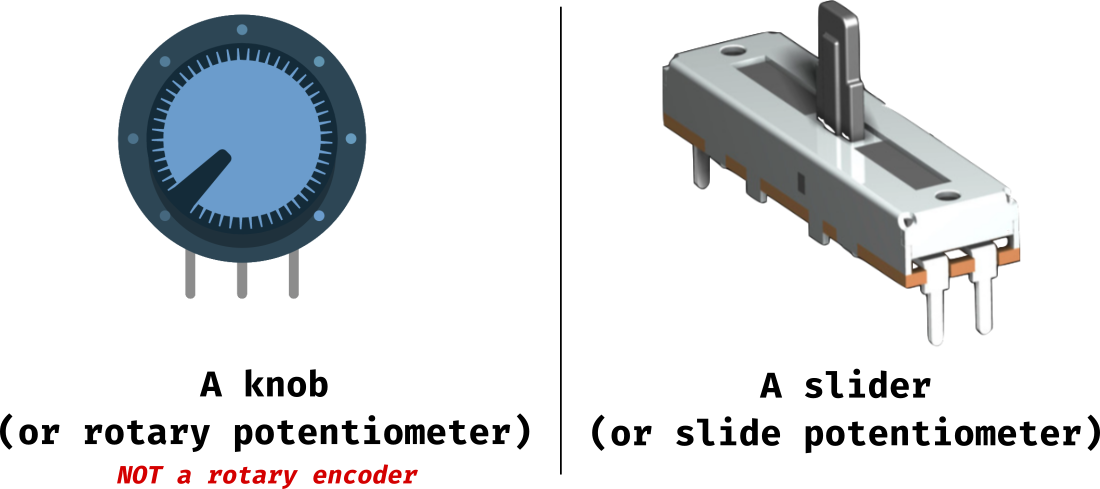
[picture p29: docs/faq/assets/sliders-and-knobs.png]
Sliders and knobs


<sub>_Tags: #potentiometers, #pots, #sliders, #rotarypots, #knobs_</sub>

[**[↑]**](#deej-faq)

### Does the resistance of my pots matter? Do they need to be 10K?

In short: **no, it doesn't matter.** Any resistance will work.

Longer explanation: deej uses potentiometers as voltage dividers between a 5V pin and a GND pin. Since each analog pin (the pin connected to the pot's wiper) has its own "circuit", each pot is treated as its own voltage divider and is always the only resistor across that circuit. This also means that some of your pots can have one resistance and other ones a different one. It just makes no difference in the context of this project. [Here's a great video](https://www.youtube.com/watch?v=fmSC0NoaG_I) if you're interested in learning more about voltage dividers.

<sub>_Tags: #pots, #resistance, #10k, #ohm_</sub>

[**[↑]**](#deej-faq)

### How should I logically/electronically wire my pots together?

There are two main options to wire your pots between one another.

- The first is to "daisy chain" them (left) - each pot's positive pin connects to next pot's positive pin, with the last one going to the board. The same goes for the negative pins. You'll need to cut your wires to size for this to look good.
- The second way is to just bring out a separate wire from each pot, and twist together the _exposed_ ends to one wire (which then goes to the board). This is also done one for all the positive pins, and once for all the negative pins. This method is a bit easier to do if you have thin, flexible wires.

> **Note:** these drawings can also be followed with sliders (slide potentiometers) - rotary pots are used here as an example.

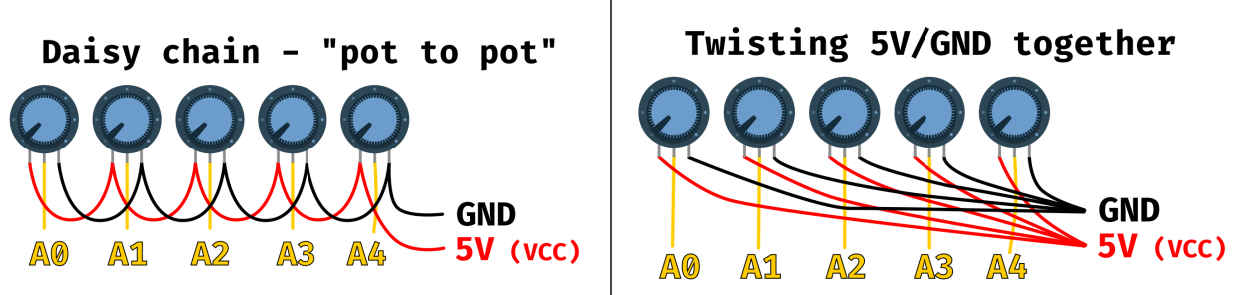
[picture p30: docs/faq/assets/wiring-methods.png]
Wiring methods


<sub>_Tags: #wiring, #potentiometers, #pots, #sliders, #rotarypots_</sub>

[**[↑]**](#deej-faq)

## Arduino

### I haven't used Arduino before, where to start?

First off, know that you're in the right place. This project is excellent for a total beginner without any electronics or Arduino knowledge. That being said, you are expected to learn some basics along the way. Here's a general suggestion for how to proceed:

- Watch an introductory video explaining the basics of Arduino, such as [this excellent one](https://www.youtube.com/watch?v=nL34zDTPkcs).
- Determine what type of deej build you want to go for (3D-printed or not, knobs or sliders, how many of them, etc.), according to your preferences
  - If this is your first electronics project, I wholeheartedly recommend to keep things simple and not add additional custom functionality. You can always add these later on (or build a second, third and fourth deej!)
- Get some inspiration from our [community showcase](https://showcase.deej.rocks) and [Thingiverse design collection](https://thingiverse.com/omriharel/collections/deej)
- Become somewhat familiar with how deej works. A great way to do this is to read the [how it works](https://github.com/omriharel/deej#how-it-works) section in the main README, or to simply read through most of this FAQ :)
- Once you feel like you have a decent grasp over how deej works and what components you need, get shopping!
  - If you're doing things for the first time, it's a good idea to get a spare or two (at least for things like your board and pots) in case you mess something up. It's unlikely, but who wants to wait for a part twice as long?
- When your parts arrive, take some time to brush up and make sure you understand how you should wire everything together. You can always undo some of it, but taking a brief refresher at this point might save you some time
- If you run into issues or have additional questions (especially if they're not covered here), join our [community Discord server](https://discord.gg/nf88NJu) and ask away!

<sub>_Tags: #beginner, #noob, #newbie, #firsttime_</sub>

[**[↑]**](#deej-faq)

### How can I find my COM/serial port?

**Windows users:**

In most cases, you would be able to see your device in the Arduino IDE, under the _Tools_ → _Port_ menu.

> _Note:_ `COM1` is reserved for use by the operating system, and very likely isn't the port of your board. If this is the only option you're seeing, your computer isn't properly detecting your board (see [here](#for-the-first-time-ever) for possible causes).

Another option for Windows users is to open the Device Manager (right-click the Start icon and choose _Device Manager_) and look under _Ports (COM & LPT)_. In most cases this will show the same list as the Arduino IDE, however.

**Linux users:**

Generally speaking, you'll be able to find your serial port by listing your serial devices with a command such as `ls /dev/ttyUSB*` and choosing the one that makes the most sense. You can also disconnect your device, run the command again and compare both outputs to find the one that's now missing.

> Please keep in mind that deej's config.yaml file requires you to use the full path, such as `/dev/ttyUSB1`.

<sub>_Tags: #comport, #serialport, #devicemanager_</sub>

[**[↑]**](#deej-faq)

### How can I upload the deej sketch to my board?

- Start by downloading the vanilla deej sketch from [this URL](https://raw.githubusercontent.com/omriharel/deej/master/arduino/deej-5-sliders-vanilla/deej-5-sliders-vanilla.ino), either by right-click → _Save as..._ (save the file with an `.ino` extension), or simply copying and pasting its entire contents into the Arduino IDE (replacing the current open sketch).
- The vanilla sketch is meant for use with 5 potentiometers, wired to analog pins `A0` to `A4`: `A0, A1, A2, A3, A4`. If you have more or less potentiometers, or they're wired to different analog pins on your board, you will need to modify the sketch to reflect those differences. You should do this _before_ uploading it to the board. To do this:
  - Change the number of pots on the first line of the sketch
  - Change the array of pin numbers on the second line of the sketch
  - For example, if you only need 3 pots and you wired them to `A1`, `A3` and `A5` your code would look like this:

```cpp
const int NUM_SLIDERS = 3; // instead of 5
const int analogInputs[NUM_SLIDERS] = {A1, A3, A5}; // instead of A0-A4
```

- Make sure that you've selected the correct COM port, board type and processor according to the board you're using, and that your board is connected to the computer.
- Upload the sketch by clicking the _Upload_ button in the Arduino IDE's top menu bar. This should take between 5 and 15 seconds to complete.

<sub>_Tags: #arduino, #arduinoide, #sketch, #flash, #upload, #board_</sub>

[**[↑]**](#deej-faq)

### How do I know that I uploaded the deej sketch correctly?

The best way to tell is to check the Serial Monitor in Arduino IDE right after your upload has completed. If it displays a steady stream of numbers, separated by the pipe (`|`) character, you've correctly uploaded the deej sketch.

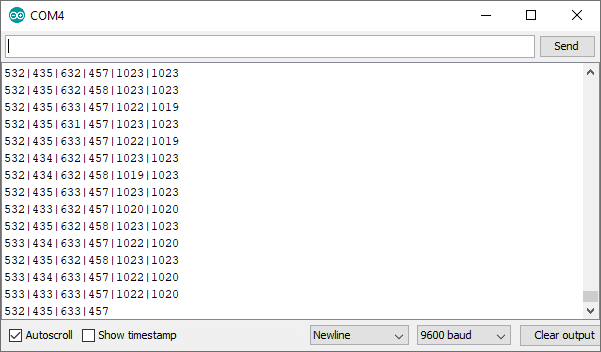
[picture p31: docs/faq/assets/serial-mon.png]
deej's serial monitor output


There are several things you want to note here:

- Each line contains a total amount of numbers equal to how many potentiometers you have defined in the sketch you uploaded.
  - The above screenshot, for instance, represents 6 sliders. The last line doesn't count, it's still being written!
- Each number corresponds to a certain pot, from left to right. Its value is a number between 0 and 1023, where 0 means "the pot is at 0%" and 1023 means "the pot is at 100%".
  - In the above screenshot:
    - the first pot sits at about 50%
    - the second and fourth pots are slightly below that
    - the third pot is slightly above that
    - the fifth and sixth pots are at 100%
- Try moving your pots! They should behave as explained above, with each one being adjustable between the range of 0 and 1023. If this isn't the case, you might have miswired your potentiometers.
- Analog values from pots are slightly different between lines, even when the pot isn't being moved. **This is normal!** Since this is an analog signal, it is subject to some noise and interference. deej internally manages that to ensure that volume only changes when you mean to change it.
  - If your analog values are "jumping" by a significantly larger margin than shown here, you may have miswired your potentiometers.

If your serial monitor appears to be similar to this, and behaves correctly when you move all of your pots, you're good to go! Close the serial monitor, and proceed to [download and set up](https://github.com/omriharel/deej/releases/latest) deej's desktop client and its config.yaml file.

<sub>_Tags: #arduino, #arduinoide, #sketch, #flash, #upload, #board, #verify_</sub>

[**[↑]**](#deej-faq)

### I'm unable to connect to my board in the Arduino IDE...

#### ...for the first time ever

You might be **missing drivers** that correspond to your board. This is of course going to depend on which board you got (with most drivers being automatically detected and installed by your OS), but a very common driver that cheaper Nano-like boards use is the CH340.

> Please keep in mind that you should only use drivers provided or instructed by your board's manufacturer. Installing drivers from a third-party website is at your own risk.

Another common issue with some older Nano-like boards is simply **choosing the wrong processor** in the Arduino IDE, thus not being able to properly communicate with the board (despite setting the correct COM port). In this case, try choosing the **Old Bootloader** option under _Tools_ → _Processor_. You might have to restart your Arduino IDE after.

<sub>_Tags: #connectionissue, #connectionerror, #arduinoide, #accessdenied, #unabletoconnect, #board_</sub>

[**[↑]**](#deej-faq)

#### ...after connecting successfully in the past

First, **check that you've set the [correct COM/serial port](#how-can-i-find-my-comserial-port)** in Arduino IDE. Sometimes (especially during initial setup) this port will change between cable/USB port disconnects and reconnects.

Secondly, is anything else running on your machine that might be already connected to the serial port? **Only one thing can be connected to the same serial port at the same time!** Some common culprits include:

  - Cura, a popular 3D slicing software
  - Another instance of Arduino IDE
  - and of course, deej itself!

<sub>_Tags: #connectionissue, #connectionerror, #arduinoide, #accessdenied, #unabletoconnect, #board_</sub>

[**[↑]**](#deej-faq)

### How do I view the serial monitor?

First, ensure that no other program (besides Arduino IDE) is connected to the board's serial port. _This includes closing deej, in case it's already running._ Secondly, make sure that you've correctly selected the COM port in the Arduino IDE under _Tools_ → _Port_.

At that point, you should be able to go to _Tools_ → _Serial Monitor_ in the Arduino IDE (or simply use the keyboard shortcut, <kbd>Ctrl</kbd> + <kbd>Shift</kbd> + <kbd>M</kbd>). You should now see the serial output from your board!

<sub>_Tags: #serialmonitor, #arduino, #output, #arduinoide_</sub>

[**[↑]**](#deej-faq)

## Running deej for the first time

### All of my pots are inverted

This can happen if you wire their two GND/5V ends opposite to how you'd expect them to work. If you don't want to resolder anything, you can also set the `invert_sliders` option in the config.yaml file to `true`.

> Please keep in mind that if you wired hardware switches to cut power to your sliders (for a purpose like mute toggling), it would instead be treated as sending 100% volume. In this case, you'll need to resolder your pots or modify the Arduino code (and not use `invert_sliders`).

<sub>_Tags: #pots, #sliders, #invert, #reverse_</sub>

[**[↑]**](#deej-faq)

### One of my pots is inverted

In this case, simply flip the two power pins on the single problematic pot. You can also modify the arduino code to only invert that pot's value, but you probably shouldn't.

<sub>_Tags: #pots, #sliders, #invert, #reverse_</sub>

[**[↑]**](#deej-faq)

## Editing the config file (config.yaml)

### How do I open and edit the config.yaml file?

The `config.yaml` file is a simple text file, and can be edited with _any text editor_. The simplest one on Windows is **Notepad**, but you can use a more advanced editor like **Notepad++** or **Visual Studio Code** if you prefer.

> **To open the file with Notepad:**
> 1. Right-click the `config.yaml` file
> 2. Choose "Open with"
> 3. In the window that opens, double-click Notepad

<sub>_Tags: #config, #configuration, #edit, #open, #yaml_</sub>

[**[↑]**](#deej-faq)

### How can I check my config.yaml for errors?

You can easily make sure that your config.yaml is correctly structured. Just open a website such as [this one](https://codebeautify.org/yaml-validator), and paste your file contents into it. If there are errors, the website will also point out where they are.

<sub>_Tags: #config, #configuration, #check, #validate, #yaml, #formatting_</sub>

[**[↑]**](#deej-faq)

### How do I add an app to the config.yaml file?

Adding apps to the config.yaml file is simple. Start by [opening the file](#how-do-i-open-and-edit-the-configyaml-file) and pay attention to the `slider_mapping` section in it:

```yaml
slider_mapping:
  0: master
  1: chrome.exe
  2: spotify.exe
  3:
    - pathofexile_x64.exe
    - rocketleague.exe
  4: discord.exe
```

> **Important:** the slider numbers in the config start from 0, and **shouldn't be changed** depending on which pins are used. They are **always** from 0 to (however many sliders you have - 1).

To change which app (or apps) are bound to each slider, simply add their process (.exe) name under the relevant slider's number. In this above example:

- Slider #1 is bound to `master` (controls the master volume)
- Slider #2 is bound to Google Chrome
- Slider #3 is bound to Spotify
- Slider #4 is bound to **both** Path of Exile and Rocket League. You can add as many different apps as you wish to a single slider!
- Slider #5 is bound to Discord

Other than defining groups of apps, you can use other powerful options in your `slider_mapping`. Most notably:

- `deej.current` will change the volume for the currently active window
- `deej.unmapped` will group together all apps that aren't bound to a slider. This is perfect for a slider to control all your games!
- `mic` can be used to control the _input_ volume of your microphone.

> You can check out a complete list of configuration file options [here](https://github.com/omriharel/deej#slider-mapping-configuration).

<sub>_Tags: #app, #config, #configuration, #add, #set_</sub>

[**[↑]**](#deej-faq)

### How can I find the .exe name of `insert-app-here`?

If you're not sure what's the .exe name for the app you wanna add to deej's config.yaml file, you have a few options for how to find it.

**Option 1: Task Manager**

1. Open Task Manager (Ctrl+Shift+Esc)
2. Under the "Processes" tab, find the application you care about
3. Click the expand (>) button left of its name
4. Find the application name in the expanded view, and right-click it
5. Click "Go to details"
6. The process name should now be highlighted in the "Details" tab

In some cases, the app you're chasing is playing audio from a secondary process with a different name. This can be harder to find with Task Manager. But there are more ways!

**Option 2: Run deej in debug mode**

Keep in mind that this is a bit more complicated. You'll need to start by grabbing the debug executable of deej (`deej-debug.exe`) from the [releases page](https://github.com/omriharel/deej/releases) and downloading it to the same location where your deej.exe and config.yaml are:

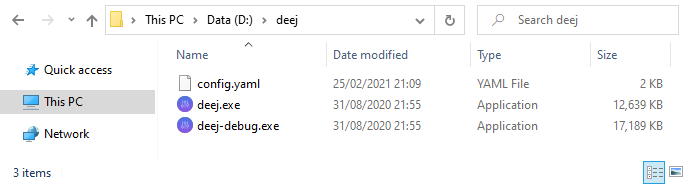
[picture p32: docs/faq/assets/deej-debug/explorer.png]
deej-debug.exe


After this, click the address bar and type `cmd.exe` then hit Enter. A command prompt window will open.

cmd.exe

Before you continue, make sure to **quit deej if it's already running** in your tray!

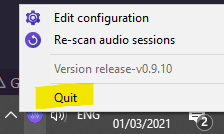
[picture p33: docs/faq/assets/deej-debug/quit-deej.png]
quit deej


At this point, make sure that your desired app is playing some audio, and then type `deej-debug.exe` in the newly opened command prompt and hit Enter. Take a moment to observe the printed logs from deej - you might need to do a bit of scrolling to find what you're looking for. Here's an example screenshot illustrating what to look for:

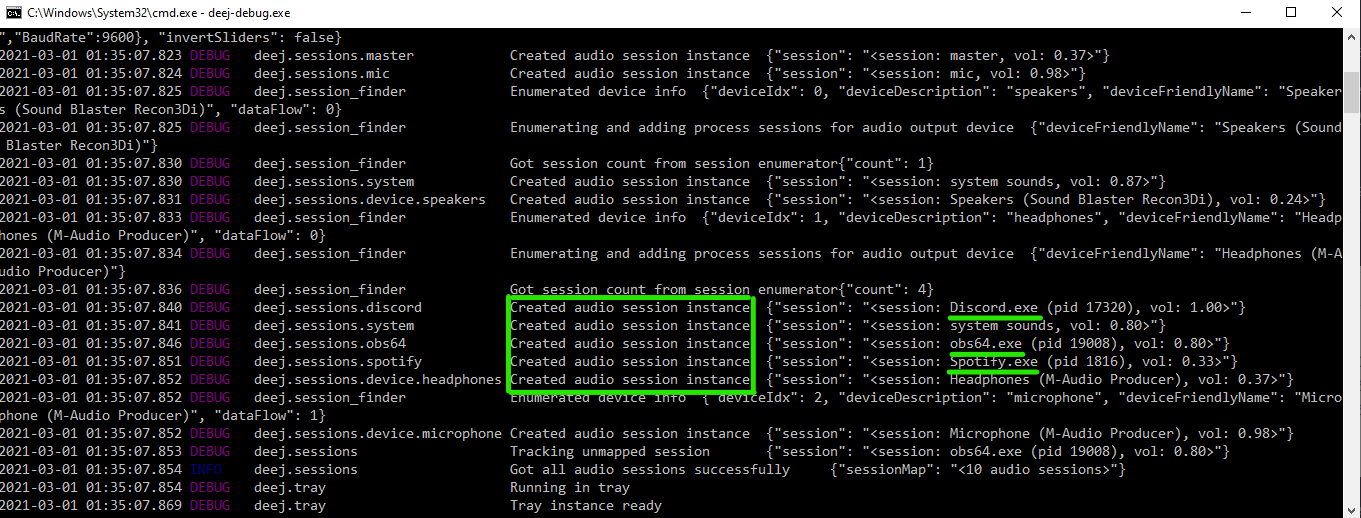
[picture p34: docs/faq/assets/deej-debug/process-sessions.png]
app sessions


<sub>_Tags: #app, #exe, #process, #name_</sub>

[**[↑]**](#deej-faq)

## Everyday deej usage

### Can I put all my games on one slider without needing to add them one-by-one?

Yes. You can use the `deej.unmapped` option to bind all apps that aren't bound elsewhere in the config.yaml file. This can be used on its own, or together with other binding options on the same slider.

<sub>_Tags: #games, #unmapped, #unbound, #onebyone_</sub>

[**[↑]**](#deej-faq)

## Component housings and enclosures

[**[↑]**](#deej-faq)

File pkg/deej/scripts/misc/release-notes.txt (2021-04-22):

This release ___________:

- One awesome thing that happened
- Another awesome thing

**Launch instructions**

- **First-time users:** download the [Arduino sketch](https://github.com/omriharel/deej/blob/master/arduino/deej-5-sliders-vanilla/deej-5-sliders-vanilla.ino) and upload it to your board ([see full instructions here](https://github.com/omriharel/deej#build-procedure))
- Download both `config.yaml` and `deej.exe` (below, under _Assets_) and place them in the same directory
- Verify that your config has the correct COM port for your Arduino board
- Launch `deej.exe`. You can always edit the config while deej is running

**_Linux users:_** for the time being, please build from source. You'll need `libgtk-3-dev`, `libappindicator3-dev` and `libwebkit2gtk-4.0-dev` for system tray support. If there's demand for precompiled release binaries, please [let us know!](https://discord.gg/nf88NJu)

> _Tip:_ If `deej.exe` seems to crash or doesn't start, please [send us](https://discord.gg/nf88NJu) the `logs\deej-latest-run.log` file from your `deej` directory.

> _Tip:_ `deej-debug.exe` is a version with a console window that displays additional logs. If you have trouble getting things to work, [join our Discord](https://discord.gg/nf88NJu) and post a snippet there.

More detailed instructions and documentation are in the [repo's main page](https://github.com/omriharel/deej).

Enjoy!

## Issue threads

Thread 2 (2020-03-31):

deej crashes everytime i try to start it

Gongal66, 2020-03-31:
Here is the error message:

Exception occurred: 'NoneType' object has no attribute 'lower'
Traceback: Traceback (most recent call last):
  File "deej.py", line 296, in main
    deej.start()
  File "deej.py", line 100, in start
    self._apply_volume_changes()
  File "deej.py", line 209, in _apply_volume_changes
    sessions = self._acquire_target_sessions(target)
  File "deej.py", line 240, in _acquire_target_sessions
    if process_name.lower() == name.lower():
AttributeError: 'NoneType' object has no attribute 'lower'

omriharel, 2020-04-01:
Hi there! Thanks for writing. Can you please attach your `config.yaml` file?

Gongal66, 2020-04-01:
# process names are case-insensitive
# you can use 'master' to indicate the master channel, or a list of process names to create a group
slider_mapping:
  0: master
  1: discord.exe
  2: opera.exe
  3: spotify.exe
  4:

# recommend to leave this setting at its default value
process_refresh_frequency: 5

# settings for connecting to the arduino board
com_port: COM4
baud_rate: 9600

omriharel, 2020-04-01:
The issue you're having stems from having nothing set for slider #5 (index 4). You have two options here:

- If you do have a fifth slider in your build, put `none` for the key `4` (e.g. `4: none`)
- If you don't have one, remove the line

Please let me know if this fixes the problem. If you need further help please reach out!

Gongal66, 2020-04-01:
Now that error dont appear, but doesnt do anything at all. Before, one sec before the error appear sometimes worked a little. Gonna try to reinstall it to see if it fixes

omriharel, 2020-04-01:
Alright. If you'd like me to guide you through it, feel free to reach out. We can talk on Discord if you need, just let me know your handle

Gongal66, 2020-04-01:
IT WORKS!!!!!! I reinstalled it and now works like a charm, really thanks for share this cool project!!

omriharel, 2020-04-01:
You're welcome! Feel free to send me a few pics of what you've built if you'd like to share, and I'll add them to the build showcase. Regardless, hope you'll enjoy it!

Closed 2020-04-01.

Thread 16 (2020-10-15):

Volume stop at about 80% and wrong Arduino voltage.

Ano10, 2020-10-15:
Hi and thanks for this software. I really like it.
Here is what happened
I'm using an Arduino Nano and plug slider to Arduino's 5V.
With this setup volume won't go up to 100%, it stops at about 80%.
Checking voltage Arduino's 5V give me around 4.6V. I've found many source on internet saying this is normal when USB powered. So calculation of voltage from potentiometer is wrong.
I check 3.3v and voltage is 3.6V (yes that's not very calibrated) and will make false calculations.

So my solution is to use AREF pin which supports 0 to 5V. Not knowing if arduino's 5V won't exceed 5V (depending of input 5V from USB), I choose to connect Arduino's 3.3v to sliders and to AREF.
I've also add "analogReference(EXTERNAL)" to setup.

void setup() {
  analogReference(EXTERNAL); // set the analog reference to the AREF pin
  for (int i = 0; i < NUM_SLIDERS; i++) {
    pinMode(analogInputs[i], INPUT);
  }

Now whatever is real value of 3v3, measurement are correct.

I don't know if code and documentation should be modified or if I'm the onlyone having this issue but I wanted to report it.

omriharel, 2020-10-15:
Hi @Ano10, thanks for writing (and thanks for the kind words).

The initial issue that you've reported usually happens to users who have incorrectly wired their sliders (most commonly due to wrong assumptions about their slider's pin layout). I'm not completely clear on what the solution you found is, and whether it works completely (or just accidentally circumvents some of the problems you've been having).

Due to the nature of these hardware-related circumstances (whether it's faulty hardware or bad wiring), troubleshooting them in a GitHub issue could be quite tricky. I'd like to take this opportunity and invite you to join our community [Discord server](https://discord.gg/nf88NJu). It's full of people who are always happy to help with debugging and solving hardware issues like this one - please feel free to reach out!

Ano10, 2020-10-16:
In fact I haven't received my sliders yet, so I'm using a potentiometer.
One outer pin goes to GND, other outer goes to 3.3v and middle pin to analogic input A0.
Arduino can't produce good 5V when connected to USB, but 3.3V may be correct on good quality board.
Arduino is not very accurate at reading voltage, specialy if not using outside reference. Measure can be correct on good quality board with rock solid 3.3V. Mine is not ... :blush:
Some interesting intel [http://www.skillbank.co.uk/arduino/measure.htm](http://www.skillbank.co.uk/arduino/measure.htm)

omriharel, 2020-10-16:
Thanks for the info. Sliders and regular potentiometers are electrically identical, so I use the two interchangeably :)

We've never seen this kind of issue even on cheap clone boards. Potentiometers that were wired correctly would always produce the full 5 volts, perhaps the board you're using is the problem. You should be able to wire your pots to 5v, run the original Arduino sketch and not worry about voltage read accuracy too much (deej has an adjustable built-in noise reduction system to help with the inevitable noise originating in hardware).

Ano10, 2020-10-16:
That's weird !
With deej, we're not making a voltmeter, we don't need reference voltage to calculate precise voltage.
We only mesure variation of whatever voltage and no need for this voltage to be accurate.
So I uploaded original project code and rewired my hardware... and it works flowlessly ! :open_mouth:
I maybe had bad connection or damage wire... :angry:
Thanks @omriharel for helping me and your quick answers, sorry :pray: to have waste your time.

omriharel, 2020-10-16:
Hey @Ano10, no worries at all! Glad you ended up figuring it out and solving the kinks. I hope you enjoy deej, and let me know if you run into any problems in the future!

Closed 2020-10-16.

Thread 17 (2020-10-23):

Deej prevents computer from sleeping?

Kickbut101, 2020-10-23:
I have since using Deej noticed my computer no longer stays asleep when I put it to sleep.

I originally thought it was my USB 3.0 controller (and in fact the hardware ID 1 was pointing to that) but have since resolved that. Now when I go to sleep I get a lastwake notification with an "Unknown" and the only way I get it to go away is if I unplug my deej arduino before sleep. Then my computer stays asleep just fine.

I assume the constant polling of the knobs/potentiometers sends signals back to the PC and keeps the computer from successfully staying asleep.

Any suggestions/advice?

omriharel, 2020-10-23:
Hey @Kickbut101, thanks for writing!

I'm looking into this. I think the best way that we could figure this out is by getting more inputs from our community of users (as I personally don't use sleep, at least not that I'm aware of). I went ahead and asked about this in our Discord server, and I'll update you as answers start coming in.

I'll also be on the lookout on my own PC, because I'm fairly sure it _does_ come back from sleep after it's been idle for a while.

Just to be sure we're on the same page, would you mind describing your current power settings and sleep scheme? What's your daily routine with regards to putting your computer to sleep? Do you do it manually or via a timer? The more details we have, the easier it might be to reproduce.

Thanks!

Kickbut101, 2020-10-23:
It's really easy to test. Just try putting your computer to sleep. If it _immediately_ comes back on you are experiencing the same issue I am.

Heres (probably) the part you care about in sleep settings;
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

My routine is that I occasionally want to put my computer to sleep instead of shutting it down, I manually do it.

omriharel, 2020-10-23:
Hey @Kickbut101,

So I tried doing what you suggested, and put my PC to sleep while deej was running. It did not wake immediately. After a few minutes I woke it manually, and deej even continued to work as if the connection was never interrupted (which honestly surprised me).

I still can't rule out that this isn't an issue with deej, but it does appear to be at least somewhat hardware-related. I don't know if that helps, but I'm using the "Balanced" power plan on Windows. Also, I examined my settings compared to those you're showing and the only ones that I have set differently are "Put the computer to sleep: Never" and "Allow wake timers: Enable".

omriharel, 2020-10-30:
Hi again @Kickbut101, following our conversation in the project's Discord I'm going to close this since we haven't been able to isolate anything to a setup other than yours - if you come across any news on that front, please feel free to re-open this issue so we can continue following up on it.

Thanks!

Closed 2020-10-30.

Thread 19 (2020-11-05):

Configurable Firmware

jeffeb3, 2020-11-05:
## Background

I think this project is great. It looks like a lot of fun, and I will end up with a pretty useful
device.

I use Linux and I have some experience with 3D printing and embedded software. I have extensive
experience in C++ and I've contributed to some projects like Marlin Firmware.

I see there is a vanilla firmware for 5 sliders and that seems very extensible. But I suspect a lot
of people would like to stretch the capability of the arduino pro micro without writing any software.

What I'd propose we do is to write a firmware that can have it's inputs and outputs generally
configurable over the serial port. This would make the firmware 20x more complicated, but we would
have confidence the code would be error free (ish) and users could add an LED, a knob, or a button
without editing the arduino C code.

## Detailed Example

There are similar systems that I am taking inspiration from. The blink firmware, for example. Or the
klipper 3D printing firmware.

The idea is that we write firmware for a specific arduino, like the arduino pro micro. In that firmware,
    we enable features like toggling an LED, reading a button, a knob or an encoder.

Then when the firmware connects to the golang process via serial, it is given configuration settings
for which components to enable and which pins they should be enabled on.

For example, the first serial messages to the arduino might look like this:

```
config_add_digital_output pin=10 id=0 inverted=true
config_add_analog_input pin=A4 id=1 inverted=false
config_add_digital_input pin=9 id=2
config_send period=30
```

Then there might be a message like this to the firmware:

```
set_binary_output id=0 state=1
```

And the periodic status from the firmware might look like this:

```
1:185|2:8,8
```

Which would mean the id=1 had an analog value of 185, and the digital input has read 8 presses and 8
releases.

I think the firmware would be pretty easy to build for something like this. The devil is in the
details. Can we easily configure a port from a String? How do we handle mistakes, like having two
things with the same id? What happens when a message is lost?

The golang part (which I know very little about) would then need to be able to have that
communication channel handle these flexible message lengths and be able to configure the firmware to
handle whatever the user wanted.

Once we have the basics done, we can more easily add in features like having a button responsible
for muting a mic, or having an LED respond to the muted state of the mic.

In the config file, I could imagine something like this:

```
volume:
 - pin: A4
   signal: master
 - pin: A1
   signal:
    - rocketleague.exe
    - pathofexile_x64.exe
   inverted: true
   noise_reduction: high
 - encoder: [D4, D5]
   signal:
   - spotify.exe
   resolution: 4

status:
 - pin: D6
   signal: mic.mute
 - pin: D7
   signal: master.mute

mute:
 - pin: D9
   signal: master
 - pin: D10
   signal: mic

connection:
  port: COM4
  baud_rate: 9600
```

## Other benefits

This would mean that the firmware would stay relatively close to the same in most builds. The
advantages of that are:

 - A lot of people using the same software build would make it more robust.
 - Effort spent on improving the firmware would be useful to more people.
 - A lot more flexability without needing to spend much time in the firmware.
 - Some enterprising individual could sell the pro micros with the firmware already flashed. That would
 help a lot of people get started who are intimidated by the firmware. I wouldn't do that (I am too busy                                                                                           anyway).
 - You could add even more complicated firmware features, such as keyboard emulation, encoder knobs,
 or displays. Even input or output matrices, such as the ones used in LED cubes or olkb keyboards would be possible.
 - After defining a generic serial port interface, new boards would be able to be built with new
 firmware and concrete requirements.

## How do we get there?

I think this is a lot of stuff to add. I personally am most interested in defining the serial
communications and writing the firmware for the arduino. But it won't work without the golang serial
support. And there won't be much benefit until there are new features added to the golang software
for these extra types of controls.

omriharel, 2020-11-06:
Hi there @jeffeb3, thank you for your incredibly detailed write-up! I'm happy to hear you like deej.

I share a lot of the same sentiments with regard to users being able to extend the project and take full advantage of the hardware they're building with, however I do think that the way there needs to look differently. There are several main reasons in play here:

- **Simplicity above all else:** one core reason that the project got to where it is, IMO, is how simple it is to assemble and configure it (even if you're a complete Arduino or electronics beginner - just like I was when I started it). It is crucial to maintain that. I would say a good rule of thumb is: "does the user's config file require any knowledge about pin numbers?" - if the answer is "yes", it's too complex to put in the hands of users who e.g. receive deej as a nicely wrapped gift.
- **Customizability should be trivial when possible.** If users need to learn the intricacies of the serial protocol to take advantage of custom features (even if they're exposed via config - which is also somewhat tricky to teach users, even if it's simple), it has the risk of feeling like a step backwards from simply adding a few lines to your Arduino code to e.g. achieve a mute toggle or color an LED ring.
- Similarly to the config, the serial protocol shouldn't be aware of pin numbers. Communication between the client and the firmware should happen with **application-level semantics**: "Slider 3 reads 765", "Button 1 has been pushed", "Display X should display icon Y". This is valuable for easier troubleshooting, but of course requires the firmware to be aware of these application-level concepts.

I do have a distant future plan for supporting a similar kind of extensibility in a different manner. My plan is to take advantage of code generation to build a custom firmware for the user's desired set of hardware features as selected during set-up. For example, the user would indicate that they have 5 sliders, 4 buttons and an LED ring. deej's setup would then generate a flashable firmware that supports these specific features, with pin numbers either being set manually by the user or suggested by deej, also depending on the user's choice.

This is still _very_ far down the list of things I'm planning to add. With that being said, I have a shorter-term plan to add infrastructure-level support for handling button presses over deej's serial protocol. This would allow users to easily bind buttons to several different triggers from deej's config file. These will include triggering a keyboard shortcut, running an executable, software-muting a slider, etc. Further down the line, this can be expanded to allow advanced triggers such as making an HTTP request or even running custom Go code (via Golang's plugin system).

Here's where I might (understandably) disappoint you: I'm extremely passionate about my vision for the project and its future, but it is something I do in my free time and ultimately I _would_ prefer to work on all of these major things by myself. I appreciate that you've put a lot of thought into your proposal, and I strongly encourage you to explore it in a fork if you're excited to do so.

I'd like to take this opportunity to sincerely apologize if this response at all strikes you as dismissive, or otherwise leaves any sort of bad taste. It is definitely not my intention. In the coming weeks, I intend to add more details about the project's development and scope to a `ROADMAP` file. I hope this will help people who find themselves in a similar situation down the line to manage their expectations.

I look forward to hearing your thoughts about any of the things we touched on here, and please also feel free to reach out privately to me via the project's Discord server if you prefer that.

jeffeb3, 2020-11-06:
>     * "does the user's config file require any knowledge about pin numbers?" - if the answer is "yes", it's too complex to put in the hands of users who e.g. receive deej as a nicely wrapped gift.

This is a really good point. I assumed the users are involved with the soldering of the project, and they would understand where the pins were on the board.

My first thought is that maybe the configuration could be layered into a hardware abstraction layer and an application layer. The hardware layer would set up `slider3` and then the application layer would look a lot the same, with the config associating slider3 with the master volume.

I think we could also create good ways to handle hardware customizations we haven't thought of. By creating a well defined serial layer, which includes specific ls for custom components, makes it easier to edit, not harder. Inevitably, someone will make an led ring and someone else will have a wheel encoder and then a third person will want both.  Keeping the pin assignments on the software/golang side just makes it much easier to change. But it could also be handled in the firmware. I cringe thinking that each user is making their own serial protocol and has to reinvent new customizations.

And I'm not offended at all. I really appreciate the honestly and if I sound ungrateful or critical, understand that I am just trying to express my point clearly and quickly. No worries.

Closed 2020-11-06.

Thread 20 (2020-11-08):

Volume doesn't go all the way to 0 or 100%

nokarukuta, 2020-11-08:
I have some cheap sliders so the values in serial monitor don't go all the way. The lowest I can get it is 22 and the top sometimes barely makes it to 950. Is there a value I can change that accounts for that? It shouldn't be a problem but it turns out that even at 2% volume in Volume mixer stuff applications are still audible.

omriharel, 2020-11-08:
Hi @nokarukuta, thanks for writing.

There are two things you could try:

- setting `noise_reduction` in your config file to `high` would make your volume adjust at 4% increments. This may be sufficient for ~22 in serial monitor to count as a 0.
- alternatively, if you're comfortable manually editing the Arduino sketch, you could use the `map` function to remap the values of your sliders from the range you're seeing to 0-1023.

That aside, are you sure you've wired up your sliders correctly? This shouldn't really happen unless one or more analog pins are subject to some signal noise.

Also, please feel free to join our Discord server if you'd like more active help troubleshooting - GitHub can be a bit of a tricky platform for that :)

nokarukuta, 2020-11-11:
Thank you very much for the quick response!
The noise_reduction setting is something I've tried before and it didn't help. Anyway I tried editing the sketch:

```
void updateSliderValues() {
  for (int i = 0; i < NUM_SLIDERS; i++) {
     analogSliderValues[i] = analogRead(analogInputs[i]);
     analogSliderValues[i] = map(analogSliderValues[i], 25, 950, 0, 1023);
  }
}
```
But it seems that I'm doing something wrong since only the first slider now works in deej. Which is strange because all 5 values in Serial Monitor show the remapped numbers.

omriharel, 2020-11-12:
Hey @nokarukuta,

The values you're giving as an example aren't properly constrained to be a 10-bit number. Values sent to deej must always be between 0 and 1023. Try adding the following line after the `map` statement: `analogSliderValues[i] = constrain(analogSliderValues[i], 0, 1023);

nokarukuta, 2020-11-12:
Well that fixed it! Thank you very much for your time and for making this project! It's one of those thing you never knew you needed, but are so useful you can never go back after having them

Closed 2020-11-13.

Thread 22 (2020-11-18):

Feature request: Change output device with switch

jordaneast1, 2020-11-18:
HI! This looks awesome & I'm keen to have a go making one 👍

I use a 2 output audio interface which is super handy as I can have different outputs for my headphones and speakers.

It would be so awesome if i can switch the output devices of my apps on the go with deej.
Ideally I would have a switch below each slider that would choose either my  ZEDi10 ST2 or ZEDi10 ST3 device (see picture of my normal app device setup)

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

Is this possible with the Go app? I'm not too familiar with Go, but I know arduino well.
If you can point me in the right direction as to where i could implement this that would be awesome.

Thanks

omriharel, 2020-11-18:
Hi there @jordaneast1, thanks for writing! I'm glad you like deej :)

I'd like to treat your question as two separate ones, with the first being about switching output devices altogether and the second one about doing it on a per-app basis. The TL;DR for these would be that (1) is possible via some means but not supported officially (and isn't planned to, due to reasons I'll go into momentarily) and (2), AFAIK, isn't possible.

**Switching devices (altogether)**

Unfortunately, at the time of writing switching output devices programatically (via Windows Core Audio APIs) isn't supported by the OS. Microsoft has somewhat sensible reasoning for this, in that they don't want vendor software to potentially clash with one another and cause conflicts, but the implication is that nobody else can set that preference other than the user (via their Windows Settings panels).

There are several external applications available that _do_ support switching audio devices on your behalf, and they do so using reverse-engineered, undocumented APIs that mimic what the user would have to do in order to set the preference. I don't plan to do the same as part of deej, because undocumented APIs are by definition unstable and can break without any notice. I also don't want to package external apps with deej (or rely on them being installed separately), so for now I have no plans to support this.

There is a fork of deej called [Phenipa/deej_toggle](https://github.com/Phenipa/deej_toggle) that supports toggling output devices in response to a button press by relying on you running one such external program (and triggering a keyboard shortcut that it listens on). This is currently the only good option for this use-case, but again - it's not officially supported and isn't guaranteed to keep up with newer deej releases. You'd also have to build deej yourself, but I imagine that's not a problem.

**Switching devices (per-app)**

I don't have much to say about this, except that I don't think that it's possible (at least not trivially). Since Windows doesn't support programatically switching output devices in general, I doubt it would include support for switching them for other apps. Of course, all apps that _produce_ audio have the ability to route their audio to whichever device they want - the preference window from your above screenshot is just a default, but can be overridden by the software (i.e. if set explicitly by the user in that software's preferences).

I'm sure with enough reverse-engineering skills you'd be able to figure out a way to do this, but the walls you'd encounter would be at the Windows level anyway - adapting Windows API calls (via COM/OLE) to Go won't be the hard part here.

**In summary**

While I haven't given you a decent solution, I hope I managed to somewhat paint the landscape of what your options are with the knowledge I have. If you have any more questions, please don't hesitate to ask!

jordaneast1, 2020-11-19:
Thanks so much for the great response!

This is all really useful to know, and SoundSwitch looks like it could be a good solution. for at least having some functionality to switch between my two outputs.

Per-app would be ideal but yes it looks like it would be some reverse engineering! Thanks for pointing me in the right direction.

Interesting, I did not think about changing the in-app settings, perhaps i could do that through hotkeys for each app. But seems like a lot to figure out as I'm using a wide range of software (Adobe, chrome, spotify... list will go on)

Another not as fun but much easier solution would be to have a button on my deej controleer that simply opens the App volume device preferences, I and I can change it manually from there...
at the moment I have a desktop shortcut that runs the program:

`C:\Windows\System32\cmd.exe /k Start ms-settings:apps-volume && exit`

which nicely opens the right settings panel with the URI command `ms-settings:apps-volume`

perhaps i could integrate that somehow into deej?

Thanks!

omriharel, 2020-11-19:
Hey @jordaneast1,

If you're going to go with the fork I mentioned, you should be able to fairly trivially add support for a second button and respond to it by launching the above command as a process (I think deej already has _some_ logic for launching a process implemented, because it supports opening the config file for editing from the tray menu).

In the future, native support for buttons over deej's serial protocol will be added and then you'll be able to bind them to actions (such as pressing a keyboard shortcut or executing a command) right from your config file - but there's no time frame for this yet.

omriharel, 2020-11-23:
Closing this for now - please feel free to open a new issue if you have any other questions :)

Closed 2020-11-23.

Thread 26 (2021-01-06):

"mic" slider doesn't affect capture level with some microphones

Kwimbee, 2021-01-06:
Hey,

Amazing project ! I love it !

Theres a small issue i'm having, the mic mapping doesnt seem to work for me.

Here's my slider mapping :

```
slider_mapping:
  0: chrome.exe
  1:
    - discord.exe
    - skype.exe
    - zoom.exe
    - teams.exe
  2:
    - tidal.exe
    - tidalplayer.exe
    - spotify.exe
  3:
    - rustclient.exe
    - planetside2_x64.exe
    - planetside2_x64_BE.exe
  4: vlc.exe
  5: deej.unmapped
  6: mic
```

All is working fine, but the mic volume doesn't move. I've also tried the following mapping, without success :

```
slider_mapping:
  0: chrome.exe
  1:
    - discord.exe
    - skype.exe
    - zoom.exe
    - teams.exe
  2:
    - tidal.exe
    - tidalplayer.exe
    - spotify.exe
  3:
    - rustclient.exe
    - planetside2_x64.exe
    - planetside2_x64_BE.exe
  4: vlc.exe
  5: deej.unmapped
  6: Microphone (AUKEY PC-LM1 USB Microphone)
```

Anything I should check ? This is what I've already checked:

- Running release-v0.9.10
- Value for the corresponding slider is well received on the serial port
- When running deej in debug mode and moving the mic slider, i receive the following lines in the console :
  `2021-01-06 22:40:02.375 DEBUG   deej.sessions.mic               Adjusting session volume        {"to": "1.00"}`
- Audio sessions seem to be found for the mic, as stated by the following console output :
  `2021-01-06 22:42:08.930 DEBUG   deej.session_finder             Enumerated device info  {"deviceIdx": 4, "deviceDescription": "microphone", "deviceFriendlyName": "Microphone (AUKEY PC-LM1 USB Microphone)", "dataFlow": 1}`
  `2021-01-06 22:42:08.931 DEBUG   deej.sessions.device.microphone Created audio session instance  {"session": "<session: Microphone (AUKEY PC-LM1 USB Microphone), vol: 1.00>"}`
- Microphone (AUKEY PC-LM1 USB Microphone) is set as my default audio input

Kwimbee, 2021-01-06:
I've just done another test, and what's interesting is that the slider in the sound properties window does move perfectly, but the mic volume is not altered.

See the following image for reference :

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

Noise still goes into discord, and green volume bars are present in the windows dialog, although the level of the mic is set at 0 by deej.

omriharel, 2021-01-07:
Hi @Kwimbee, thanks for writing!

This appears to be an issue with some USB and bluetooth microphones where they disobey that "level" slider entirely. You can try it out by closing deej and moving that slider in the properties screen from this above screenshot, and you'll see that it has no effect on mic capture level.

My guess is that the driver software for these devices either hasn't implemented proper support for that Windows API, or that they're ignoring it knowingly and purposefully. In both cases, I'm afraid you'll need to try a different mic if you'd want deej to work with it as-is.

Your other option is to add Windows-side muting (with the `SetMute` function) into deej, and enable it for anything that becomes zeroed out. This isn't implemented in deej yet, so you'll need to get your hands dirty if you go that route! If you do that, make sure that muting does actually work with your mic (that little button next to the volume level textbox).

Kwimbee, 2021-01-10:
Hi @omriharel,

Thanks for the explanation. This is a "cheap" USB webcam so yeah I wouldn't be surprised if the driver is not perfect.

Regarding the use of the SetMute function, I'm not too fluent in Go and I don't know the Windows API regarding audio stuff, so I don't really trust myself doing it.

Is this something that is on the deej roadmap ?

omriharel, 2021-01-10:
Hey @Kwimbee, thanks for your reply.

This is not currently on the roadmap, because muting doesn't inherently represent what the average user would want as their zero state (even though muting is indeed equivalent to zero volume, semantically speaking).

It's entirely possible that muting will be added as its own core concept at a future time, and that will likely be tied to something more binary like a button or toggle switch.

Closed 2021-01-27.

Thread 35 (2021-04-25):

Support for Raspberry Pi Pico

shaylanger, 2021-04-25:
I recently built a volume control using Deej and a raspberry pi pico, and figured others might find the python code for the pico usefull (if they wanted to build this as well using a pico)

save this code in a file called main.py on the pico and when the pico is plugged in the Deej program will be able to listen to the potentiometers (you will need to adjust the config.yaml to only  have 3 sliders)

Note the Pico only has 3 analog pins (26-28) so it only supports up to 3 potentiometers

```
import machine
import utime

NOISE = 10
POTENTIOMETER_COVERSION = 64.0625610948 #Converts the Pico's 65536 max to match Deej's expected 1023 max
POTENTIOMETERS = [
    machine.ADC(26),
    machine.ADC(27),
    machine.ADC(28)
]
values = [0] * len (POTENTIOMETERS)    

while True:
    results = ""
    for i, potentiometer in enumerate(POTENTIOMETERS):

        curr = round(potentiometer.read_u16() / POTENTIOMETER_COVERSION)

        # this check will normalize the results and reduce noise
        if values[i] > (curr + NOISE) or values[i] < (curr - NOISE):
            values[i] = curr

        results = results + str(values[i])

        if i != len(POTENTIOMETERS) - 1:
            results = results + "|"
   
    print(results)
    utime.sleep(.2)
```

omriharel, 2021-04-27:
Hi @shaylanger, thanks for writing!

This is cool, however I think it's more appropriate for it to be accessible via your fork of deej - you can essentially create your copy of the project and add the relevant code and instructions there, ensuring that any future changes you make continue to live on in that location. If that sounds good to you, perhaps you can do that and then edit the issue to link to your fork?

Please let me know if you have any questions.

omriharel, 2021-05-02:
Closing for now!

dadsgone0, 2022-09-01:
For some reason, you are the only person ive seen use a pico for a deej build, i could not find anyrthing on a deej pico build anywhere else. Thank you!

2tondo, 2024-04-08:
I had the same issue as the guy above me, love your work

akumar48, 2024-04-09:
Thanks a lot this is awesome!

Closed 2021-05-02.

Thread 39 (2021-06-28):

[Feature]Deej remember setting after reboot

oddife, 2021-06-28:
Is it possible to make deej remember the settings after a reboot?,  eg if I have the microphone muted or volume set to a specific level it should automatically remember that setting during the next startup.

omriharel, 2021-06-28:
Hi there @oddife, thanks for writing.

If you're using potentiometers, which is what deej supports, the behavior you're describing is just a consequence of leaving them at their absolute positions. At startup, deej just sets all volume to whatever potentiometer readings it gets from serial - if it didn't do that, it wouldn't be doing its primary function which is to translate analog readings to app volumes.

If you're using rotary encoders (which deej _doesn't_ officially support), these aren't absolute as they can rotate infinitely to either direction. In this case it's up to you to take care of storing their current values to persist between reboots of the _Arduino hardware_. I've seen some people use an EEPROM for this, but I haven't done this myself and I'm not sure what the actual lifespan of a solution like this is (since you'd be writing to this EEPROM quite a lot).

At any case, this is consciously out-of-scope for the project because encoders aren't officially supported.

oddife, 2021-06-29:
thank you for the replay, yes I'm using encoders as I needed to mute the inputs with that switch, EEPROM would be a bad idea so I was thinking could the software make a file that would write the values once they are changed and reload it every time the software starts.

omriharel, 2021-06-29:
As I mentioned, this is out-of-scope for deej because it doesn't include support for encoders. You can still implement it for yourself in a fork, but this isn't going to be a core feature.

Closed 2021-06-28.

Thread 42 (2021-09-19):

Invalid configiruation

blackfield3k, 2021-09-19:
Hi there,

i have the issue that if a add multiple programs to one fader like stated in the manual i get an invalid configruation file error.

If i list the programs with commas, it seems to work but not stable

EDIT: ok i used tab to arange it nicely. Seems like deej doesn`t like this. it works with spaces.

But it takes a long time till changing of volume works

omriharel, 2021-09-19:
Hi there @blackfield3k, thanks for writing.

The FAQ document (link in the main readme) has some commonly-asked questions about configuration editing, and how to make sure that your config file is valid before starting deej. I'm guessing that your config mixed tabs and spaces, which unfortunately doesn't quality as valid YAML. You should be able to use either tabs or spaces, but not both.

Regarding stablity issues, these usually have to do with unstable wiring on the problematic potentiometer (or another hardware fault with the pot in question).

Can you expand on the delay before changing volumes? It should be instant - if it isn't, there might be something else interfering with deej. This could be another audio-related software, an audio driver or a faulty sound card.

Please join our Discord server for more help with troubleshooting any issues you might have - it's usually better for this kind of thing. Thank you!

blackfield3k, 2021-09-20:
Configuration is now working fine, even with multiple apps.

I cant confirm that deej gets the values for sure but if i close deej and open a terminal values seem to change immediately. They are a bit noisy (mostly around the last digit), gonna fix that.

I think the problem is/was deej getting confused with many open instances like chrome does for every tab. As i reduced the amount of apps, the problem was gone.
But i am gonna get sure that nothing interferes with deej. Are there common suspects?

thanks for your help and this awesome piece of software

omriharel, 2021-09-20:
@blackfield3k - A tiny bit of noise is to be expected with potentiometers, and deej does have inherent noise reduction built into it. You can fine-tune it to make it a bit more or less sensitive depending on your hardware (the `noise_reduction` config setting allows that).

I don't think I heard any previous reports for many running apps making deej run slower, but here are a few things you can try:

1. Check if the issue is isolated to a specific target, whether the `master` channel of a specific audio device (i.e., if you have Speakers connected to your main sound card and USB headphones that are their own audio device, check with either of them set as the default audio output)
2. Check if you can replicate the slowness you're experiencing with deej not running - if it takes a while for Windows Mixer or the Windows volume UI to respond to your dragging, that's a pretty good indication something is wrong at the driver/audio card level. I wouldn't know how to fix that, though

Thank you for the kind words!

blackfield3k, 2021-09-23:
@omriharel - Thanks for your suggestions. A 470uF cap between GND and 5V did the trick. Pots are now stable.

On first: it disappeared after i wrote my config.yaml completely new. What ever this was, it is gone.

What i suspect that cura interfered with the serial data stream, as it trys to connect to everything that is a virtual com port (i dont care if you are a 3D printer or not - i will connect)

But great work and keep it up!

Maybe in the future it would be nice not only to read from the controller but also write to it

Closed 2021-09-23.

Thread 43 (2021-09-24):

Volume going up and down like crazy

DJVibezzz, 2021-09-24:
Hello,

Just as the title says, it happens when I start up the software or debug software.
The volume is going from 0 to 100 to 0 etc very fast.
how do I fix this issue?

this is my log:
[deej-latest-run.log](https://github.com/omriharel/deej/files/7228025/deej-latest-run.log)

omriharel, 2021-09-25:
Hi there @DJVibezzz, thanks for writing.

It sounds like there is a wiring issue with the potentiometers you're using. The best way to get accurate and effective help with this kind of issue is to join our Discord server, where we have a dedicated channel to helping people solve this type of problem (which is especially useful if this is your first electronics/Arduino project).

It's also a good idea to read through our [FAQ](https://discord.com/channels/702940502038937667/703517816447565884/743193392531374112), where you'll find a detailed explanation for how to troubleshoot deej's hardware components using the serial monitor.

Please let me know if you have any additional questions. Thanks!

Closed 2021-09-26.

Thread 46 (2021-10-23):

Deej.exe does not work with windows 11?

nabeelmoeen, 2021-10-23:
looks like Windows have finally changed how the volume control works and removed the legacy mixer.
https://www.windowscentral.com/hidden-changes-you-may-have-missed-windows-11

I tried the deej.exe on my windows 11 setup, i can see the serial output changing on moving the sliders (on the arduino serial monitor), but the windows volume isn't moving.

nabeelmoeen, 2021-10-31:
Thank you @stephensilber and @NegussugeN.

I will chalk this off to user error.
running as administrator worked for me, also, 2 of my potentiometers seemed to be faulty.

omriharel, 2021-11-13:
Hi there @nabeelmoeen and @stephensilber - apologies for not responding earlier, it's been quite a busy time for me!

I hope you're enjoying deej. I have a few quick questions about the solution you found, that might help shine a light on this for other users who see this thread in the future.

1. Did you previously use deej with Windows 10, or did you try it on Windows 11 for the first time?
2. If you've used deej previously on Windows 10: where (in what directory) did you place its executable on your PC? Did you need to run as administrator back then?
3. Where is the deej executable currently placed on your Windows 11 PC?

The reason I'm asking this is because I suspect that nothing changed between Windows 10 and 11 in terms of the permissions that deej inherently requires, and by default deej doesn't (and shouldn't!) need any special permissions to run. But there is one soft limitation on both Windows 10 and (I suspect) Windows 11: deej has to be inside a directory that doesn't require admin privileges to access, otherwise it can't open its logfile for writing.

For many users, placing the directory with deej's executable on their desktop or in another directory that they have full access to (such as in `C:\deej`) worked fine, whereas using a system location like `Program Files` or their user directory would fail and require them to (unnecessarily) use the "run as administrator" option.

If that's the case on your end, I'd love to hear if moving deej (and its config file) removes the restriction of needing admin privileges to run. Thanks for taking the time!

JeanCharpentier, 2022-08-15:
Hello !
I know this topic is old, but I had a similar problem. After upgrading to Windows 11, Deej was not able to manage audio.
**What worked for me** was to disconnect and reconnect the Arduino, and "sync" it with the Arduino App. Once done, I started Deej and voila !
Hope this will help.

Closed 2021-10-31.

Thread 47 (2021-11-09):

Serial connection frequently stops in Windows

ThreepE0, 2021-11-09:
I've found that almost more often than not, when I reach for my Deej mixer, it simply doesn't work until I restart the Deej app.  I've worked around the issue by adding a Windows task scheduler item to restart the app every five minutes, but there has to be a better way.

I do know it happens after sleep/resume, but I'm certain it happens at other times as well, and I'm not sure why.

Wondering if it'd be possible to at least raise a flag, make a log entry, or something else in the event that the app can't read from the serial connection.  This way I can watch that log for entries and kick off a restart, assuming the app can't recover from whatever is wrong itself.

ThreepE0, 2021-11-12:
as a quick update:  I noticed that restarting the app on a schedule in the background was interrupting fullscreen applications, so I had to ditch that approach.  Something else that I found works, and I wanted to mention here because it may help troubleshoot, is that editing the yaml config file's COM port setting, then waiting a second or two and changing it back, prompts the software to reload the serial connection, and the app starts working again.

I'm doing this in powershell and windows scheduler currently, and it keeps the app running pretty reliably, even after sleep which I think is the main cause, but not the only cause, of the serial connection breaking.  It'd be great if this got fixed in the app itself at some point, but this appears to be a workable solution.  The only downside currently are the annoying notifications that the config has been reloaded when my script runs.  Again, not a permanent solution, and not a clean one, but one that works for me at the moment.

I noticed in the code (I don't speak golang, sorry) that the serial connection is supposed to reload both on config file change, as well as if the app can't read lines from the serial connection.  It appears that it's not reloading when it can't read a line, but it IS reloading when there is a config change to the COM port.

omriharel, 2021-11-12:
Hi there @ThreepE0, thank you for writing!

This is a known issue - currently the only workaround I can suggest is to restart deej when the connection is interrupted. As mentioned in #38 and #23, I intend to fix this in the next release as part of an overall connection stability pass. I'll close this issue as it somewhat duplicates #38.

I will mention that these disconnections aren't expected to be a frequent occurrence, and if that's the case for you I would suggest to look into power-saving settings and other similar things that may be causing your board to disconnect even when the computer doesn't go into sleep mode.

If you have more questions please feel free to leave a comment (or contact me via the project's Discord). Thanks!

ThreepE0, 2021-11-12:
"restart deej when the connection is interrupted." I have to say I'm a bit let down by this reply, as it doesn't appear that you read or put any thought into either of my replies.  I was hoping that my comment would help you in coming up with a fix, or at least provide a data point.  I've found a workaround myself, so that base is covered.  After taking a quick look I found that, I think anyways, the serial communication failure detection that is already built into the app doesn't appear to work correctly.  Do you have any thoughts on that?

omriharel, 2021-11-12:
Hi there @ThreepE0. I did read your comments, but I don't have a better solution to offer until this is fixed properly so I was affirming your current workaround as the option I'm recommending until the next deej release.

I'm familiar with the connection mechanism in deej (having written it 😅), and I do have a concrete plan for a fix that will address all of the current issues in this area (including the one affecting your setup). Coming up with the specifics of that fix isn't an issue (the details have already been discussed - and finalized - in the project's Discord server). However, I work on deej during my free time and when my motivation allows it, so I don't have a timeline for this other than "soon". I hope that in the meantime you'll continue enjoying deej in its current state, and please do stay tuned for future updates.

ThreepE0, 2021-11-12:
Thanks for the reply @omriharel.

Again, I’m not looking for a better solution at the moment as I understand
you’ve had something in the works for a while. I am not currently
restarting the application, that is not my current workaround.  My
workaround is to edit the config’s COM port and trigger a refresh that way,
as restarting the application was interrupting fullscreen applications.

I was simply providing a behavior that I observed in the application in
hopes that it may help you in considering your solution. It doesn’t sound
like you need it though.

Anyways, looking forward to the updates.

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

Closed 2021-11-12.

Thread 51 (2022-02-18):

"System" function not working

DiopticTurtle, 2022-02-18:
Good morning,

Firstly, thank you so much for this tool; it is exactly what I was hoping it would be and it has completely changed how I manage sound on my computer in the best way.

On to my issue: it seems that the "System" fader is not changing the system volume; I can verify this by looking at the mixer and as I move the fader the System Sound level does not change. I looked at the previous issues and did not see anything that looked like it was the same issue. I can attest that it did previously function as expected, and I have never touched the config or code since I first implemented Deej.

This is not a major issue, in my opinion, and does not change my opinion of the tool, but it would be nice if I could fix it!

Thank you,

omriharel, 2022-02-18:
Hi there @DiopticTurtle, thank you for writing. And thanks for the kind words about deej!

As a first thing to try, just to make sure there hasn't been a disconnection of that specific fader at the hardware level - would you be able to assign `system` to another slider in the config, and check if that works? (Or alternatively, binding apps other than `system` to the fader in question and checking that it controls them correctly)

If you've confirmed that the issue is indeed with the `system` binding, and not with the pot itself, I would appreciate any additional information you can provide about your setup: your config file, your precise OS version (including build number), and if possible - a sample output log from deej's debug version (you can find instructions about how to run in debug mode in our [FAQ](https://faq.deej.rocks)).

Thank you!

DiopticTurtle, 2022-02-18:
Hi @omriharel , I was able to rule out hardware issue, as swapping the bindings of the Master and System faders had the same result (System fader not affecting the volume, Master fader functioning as expected).

For system info, this is a homebuilt machine and I am running a 64-bit Windows 10 Home, version 10.0.19042 Build 19042.

I've attached my config yaml (just saved it as a .txt to make the uploader happy) and the text from the Debug .exe after adjusting the Master and System pots.

[DTconfig.txt](https://github.com/omriharel/deej/files/8098914/DTconfig.txt)
[DTDebugLog.txt](https://github.com/omriharel/deej/files/8098915/DTDebugLog.txt)

Thank you for taking the time and looking into this!

omriharel, 2022-02-18:
Hey @DiopticTurtle, thanks for the details. I think some of the log contents may have been omitted (I don't see the startup and version info logs that I'm looking for), but I do have another question about your setup:

Have you been using voicemeeter throughout this entire time? I see that its audio sessions and virtual devices are detected by deej, and I'm wondering if we're not experiencing some sort of conflict with downmixing happening inside voicemeeter (which naturally is also closely involved with Windows' audio APIs). Would you be able to try re-opening deej without voicemeeter running, and report back?

The thing that seems odd to me is that deej does see a system sounds version, and does seem to be interacting with it - so it's weird that you don't see it reflected in Windows mixer. Perhaps a short screen recording of deej's log view alongside your windows mixer might help make more sense as well.

Thanks!

DiopticTurtle, 2022-02-19:
Hey @omriharel; that's a good point about VoiceMeter - let me look through the patch and see if I can find anything likely. I'll also re-run the debug and see if I can get the full thing (for some reason I guess it only captured what was on the interface at the time). I'll do a bit of experimenting and see if I can get any changes!

DiopticTurtle, 2022-03-07:
Hey, apologies for the delay in response - I am no longer experiencing the issue.
I hadn't made many changes to my VoiceMeeter setup although I did just upgrade from Banana to Potato - I had verified that my system was not trying to run system sounds through any VM channel.
I noticed that System pot was working again after I opened Sound Settings and then the Sound Device Manager; moving the pot affected the level in that application, and then it worked in the Mixer tab after that, functioning as expected. I am marking this as closed.

Thank you for your assistance, and again, apologies in the delay.

Closed 2022-03-07.

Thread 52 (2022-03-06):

Having deej open instantly wakes PC from sleep.

askolds11, 2022-03-06:
Hello!
I have an issue where having deej open instantly wakes my PC from sleep, having the Arduino plugged in doesn't matter.

From what I've read from previous threads(#17 and #21) this is what you might need:
Power options
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
Time it takes to wake after sleeping - about 2 seconds after everything turns off.
Chipset - not sure what this means, but the motherboard is a ASRock Z97 Anniversary, the wake is from
```
   Instance Path: PCI\VEN_8086&DEV_8CB1&SUBSYS_8CB11849&REV_00\3&11583659&0&A0
    Friendly Name: Intel(R) USB 3.0 eXtensible Host Controller - 1.0 (Microsoft)
    Description: USB xHCI Compliant Host Controller
    Manufacturer: Generic USB xHCI Host Controller
```
And the deej is plugged into a USB 2 port.

Everything's running and an Arduino Leonardo clone, and I have 6 potentiometers, although I'm not sure that matters, as having the program closed doesn't wake the PC.

omriharel, 2022-03-07:
Hi there @askolds11, thanks for writing.

I have heard some (relatively scarce) reports of this before, but I was never able to replicate the issue in a way that lets me dive into it more closely.

Would you be able to share a screenshot of this same panel with the rest of the settings expanded, such as "USB settings" (but not only that)? I'm sure there's a less awkward way to share this information, but I don't know what it is yet :)

Also: you mentioned that "having the Arduino plugged in doesn't matter" - can you expand on that point? Do you mean that even if you unplug your deej hardware after the deej executable has connected and continued to run in the background, that still prevents your PC from sleeping until you close deej?

Thanks!

askolds11, 2022-03-07:
About the Arduino not being plugged in - sorry, I mixed that up, since deej doesn't launch if the Arduino isn't plugged in, what I meant is that having the Arduino plugged in, but deej not open doesn't wake the pc.
Forgot to mention, I'm on Windows 11.

Here are all the power options:
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

askolds11, 2022-03-07:
I just changed the COM port in config to a different one, that isn't an Arduino (COM1, it's always there, I don't know what is is) and the computer sleeps as normal with deej open.

omriharel, 2022-03-07:
Hey @askolds11, thanks for the update.

Would you be able to try with the "USB selective suspend setting" disabled?

As a side note: `COM1` is a reserved port for the system, and I don't think deej does any meaningful interaction with it so that's likely not a great indicator for us. If you had a different board that you could try (a non-Leonardo, for example) that would probably provide us with a better distinction point - at least across the hardware side of things.

askolds11, 2022-03-07:
Changing the USB selective suspend setting did nothing.
However, I tried an Arduino Uno and that seemed to fix the sleep problem. I uploaded the sketch and verified deej was getting info to it by jumping an analog pin to GND and checking it changed the volume.
Further testing showed that an Arduino Pro Micro from AliExpress (I think it's a smaller Leonardo, based on ATmega32U4) does have the sleep issue, also verified that it's working by jumping analog to ground.
An Arduino Nano from AliExpress (old bootloader) also didn't have the sleep problem, also checked that it was working.
I've got an ATTINY85, but I haven't worked with it yet, so I'm not sure if I need a programmer for it or not and also haven't looked up the analog pins for it.

omriharel, 2022-03-10:
Hey @askolds11,

It seems based on what you're reporting that this issue is heavily hardware-dependent. This likely means that a difference in driver implementations for the various boards is responsible for the wake behavior you're experiencing.

Unfortunately, I'm not sure that this is something we're able to solve on the client side. You may want to experiment with doing some de-noising on the Arduino side and only sending a new line when a slider is moved - deej's client side would be able to handle that gracefully, assuming that the serial connection remains alive.

Please let me know if you have any questions!

askolds11, 2022-03-10:
Thank you for the answer!

I added code to check if the potentiometers have changed and if they have only then send data, and also divided and multiplied the analogRead by 2 to de-noise I guess, and that seems to have worked, as the computer goes to sleep normally and if I move a potentiometer it wakes up the PC.

Unsure how long the connection stays alive, if it has a limit, I only tried going to sleep for about 2 minutes and then waking it up.

omriharel, 2022-03-10:
Another approach for de-noising on the arduino side without losing resolution would be taking an average of the last N readings (say 10). You can also de-noise on the hardware itself by adding in some capacitors, but this may be overkill for a project like deej.

omriharel, 2022-03-13:
@askolds11 - did you get to test this further? Does the hardware-side solution work for your needs?

askolds11, 2022-03-13:
Yes it works, I haven't tried the rolling average, which would be a better way, but the dividing the readings by 10 and multiplying them again works, although I imagine it could be an issue if the reading is 119 or 120 and it fluctuates, as that would be a change and it would send data, but that's a rare enough case currently. The volume moves up/down by 4, but I think the default moved it by 3, it isn't much of an issue to me.

I'll try to make the rolling average sometime, but I currently don't have the time.

omriharel, 2022-03-13:
Okay, I'll close the issue. Feel free to add anything you want below for anyone else reading this in the future (if you do make further changes). Thanks!

askolds11, 2022-03-25:
So the division by 10 and multiplication by 10 wasn't the ideal solution, I tried the rolling average, but it didn't work as well as the previous solution and also added a delay.

Currently I seem to have fully solved the issue by sending the previously mentioned sending only when changed, but I also added a check to make sure that the values have changed by at least 3 before changing.

For anyone wondering about the code:
The checking if changed part:
Declare a variable oldValues at the start: `String oldValues;`
In sendSliderValues() add an if to check if the values have changed and also assign the current values (builtString) to oldValues:
`if(oldValues != builtString) Serial.println(builtString);
  oldValues = builtString;`

The change by at least 3 part(could be done without an extra array, but it works fine for me):
Declare a new array at the start: `int oldAnalogSliderValues[NUM_SLIDERS];`
Assign it values at setup: `oldAnalogSliderValues[i] = analogSliderValues[i] = analogRead(analogInputs[i]);`
Check if the change is less or equal to 2, and if it is, change the values to the old ones: `if(abs(oldAnalogSliderValues[i] - analogSliderValues[i]) <= 2) analogSliderValues[i] = oldAnalogSliderValues[i];`
Assign the new values to the old values after the check: `oldAnalogSliderValues[i] = analogSliderValues[i];`

Closed 2022-03-13.

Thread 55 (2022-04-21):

[Linux] Can't connect the the Arduino because the port is busy

Smart-Helper, 2022-04-21:
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

So i might need some help.

In Arduino IDE i flashed the software using the /dev/ttyUSB0 port and it worked. I can open the monitor and see the values. When i close everything that communicates with it and start deej i get this message.
How can i get this going?

Thanks in advance!

Smart-Helper, 2022-04-21:
So i know that this:
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
is the arduino nano in question.

How can i define to use that specific device in the config.yaml ?

omriharel, 2022-04-21:
Hi there @Smart-Helper, thanks for writing.

You appear to have defined the port correctly in your config (it is indeed just the full device path such as `/dev/ttyUSB0`). However, the error you're getting seems to suggest that something else is already occupying that port. Only a single thing can connect to a given serial port at one time, so if you have anything else that potentially occupies that connection (such as the Arduino IDE, its serial monitor panel, another instance of deej that might be running in the background, or simply another program that interacts with serial ports) - deej won't be able to connect.

There is a way to use `lsof` to find out which process currently uses your device, if it doesn't seem like one of the options I listed I would suggest to look for an example of that. Please let me know if you need any help there.

Thanks!

Smart-Helper, 2022-04-22:
Yeah i already checked with lsof and nothing used ttyUSB0

But i just found the culprit. I got some error on arduino when i started it and without thinking i just started it as root and it worked. And i only realized NOW that the issue i had with arduino was probably that my user didn't have permission to use the ttyUSB0

So i looked up the groupname to be used for ttyUSB0 (uucp) and put my user into it - now it works absolutely flawless and this thing is just amazing!

omriharel, 2022-04-22:
Thanks for the update, @Smart-Helper. Glad to hear it was just a permissions issue.

I guess that both missing permissions and the device being in active use result in us receiving the E_ACCESS error, so there is no great way to distinguish between the two and that'd explain why you received the "port busy" notification. I'll look into whether there's a better way to tell these apart in the future, but for now it's great to be aware of this solution.

I hope you'll enjoy deej!

Closed 2022-04-22.

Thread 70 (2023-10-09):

Default audio device changed, marking master sessions as stale

adamdiel, 2023-10-09:
I am on a new build with a fresh windows 11 install. If my computer goes into sleep and comes back I get the following error message

```
2023-10-09 16:46:59.368 DEBUG   deej.session_finder             Default audio device changed, marking master sessions as stale
```

If I simply stop/restart the exe it connects just fines and starts working immediately.

Let me know what other info I can provide!

omriharel, 2023-10-09:
Hi @adamdiel, thanks for writing.

Can you please clarify if there is any functional change to the regular operation of deej after you see this log message?

This isn't an error - it is a debug log from an internal mechanism in deej which tracks changes to your default audio playback device so that the pot you have bound to `master` sticks to whatever your current output device is.

If you are having issues reconnecting after waking your PC from sleep (which aren't related to this log message), that would be a duplicate of other related open issues such as #23 and #38. In that case, this will be fixed in a future update and you should follow those issues for an update (or our `#annoucements` channel on the project's community Discord server).

Please let me know if you have any questions!

adamdiel, 2023-10-10:
Thanks for the quick reply @omriharel !

Gotcha - I should have investigated the timestamp a little bit closer to see if it matched up.

I'll make sure to watch the Discord server! The other thing I'm going to to try is to set my power profile to high performance instead of balanced. This is the only difference I can find between my old windows 10 install and current windows 11 install.

I'll close the issue for now but if I see any change in behavior I'll report back!

omriharel, 2023-10-10:
Thanks for the update! Feel free to let me know if you observe any new behaviors.

adamdiel, 2023-10-11:
Alright reopening. I've noticed some interesting behavior that may or may not be related to deej.

So I noticed that sometimes my mouse/keyboard wouldn't wake my computer from sleep but not all the time. I figured this was a windows hibernation or a bios setting. After checking that all of that was set correctly, I started testing different ports on the tower.

I had deej running in debug and regular mode on and off throughout testing putting my computer to sleep and seeing when my mouse/keyboard would or wouldn't work to wake my device.

Findings:
1. When deej was running and the computer went to sleep, when it woke up it would always display at least one ` Default audio device changed, marking master sessions as stale` message even though the device was the same before and after sleep.
2. If deej was running and working before putting my computer to sleep mode, the mouse and keyboard would never wake the computer from sleep.
3. If deej was running but broken (because of the computer previously going to sleep) and it goes to sleep again, the mouse and keyboard work to wake the computer.
4. If deej is closed, the mouse and keyboard work in waking the computer from sleep.

Hopefully this info is helpful and let me know if there is any other info that I can provide such as hardware. Thats the only difference between where this was running and where its running now. Same hardware and slider mappings as the other box.

Here is my current config file

```
# process names are case-insensitive
# you can use 'master' to indicate the master channel, or a list of process names to create a group
# you can use 'mic' to control your mic input level (uses the default recording device)
# you can use 'deej.unmapped' to control all apps that aren't bound to any slider (this ignores master, system, mic and device-targeting sessions) (experimental)
# windows only - you can use 'deej.current' to control the currently active app (whether full-screen or not) (experimental)
# windows only - you can use a device's full name, i.e. "Speakers (Realtek High Definition Audio)", to bind it. this works for both output and input devices
# windows only - you can use 'system' to control the "system sounds" volume
# important: slider indexes start at 0, regardless of which analog pins you're using!
slider_mapping:
  0: master
  1: mic
  2: chrome.exe
  3: deej.current
  4: discord.exe
  5: XboxPcApp.exe

# set this to true if you want the controls inverted (i.e. top is 0%, bottom is 100%)
invert_sliders: true

# settings for connecting to the arduino board
com_port: COM3
baud_rate: 9600

# adjust the amount of signal noise reduction depending on your hardware quality
# supported values are "low" (excellent hardware), "default" (regular hardware) or "high" (bad, noisy hardware)
noise_reduction: low

```

omriharel, 2023-10-11:
Hey @adamdiel,

I'll comment on some of your findings, but I will preface by saying that:

- Based on the nature of these things being closely related to USB power management (which depend entirely on your motherboard/BIOS), it's very likely that _even though_ you're able to observe a correlation between deej running and wake-related functions not working as you normally expect (and the opposite) - the actual cause for it stems from having an active serial connection (and not due to some implementation details specific to deej).
- In addition, due to the highly variable nature of hardware setups, it is very difficult for individuals to reproduce issues like this
- Finally, I would like to clearly make a distinction between the serial connection becoming broken and not automatically restored after sleep (which happens, again, only on some setups - and is a known issue that's actively worked on) and other observable behaviors which you're describing above (which aren't being researched at the moment).

With that in mind:

- On point 1: The "marking master as stale" message, as described, is an internal mechanism that tracks changes to the default audio device. If it appears, it means that the OS reported that the default audio device had been changed. It doesn't necessarily mean anything for you, because it might just be power-cycling (for example if it's USB-powered, like some headphones) - but you shouldn't associate it with any adverse effects
- On points 2 to 4: they all suggest that having an active serial connection while the computer goes to sleep prevents USB wake from other devices. You can try to test if other serial connections to an Arduino board (that aren't deej) produce the same behavior, but I don't have much else to say about that - I don't consider it a deej issue at the moment

I suppose you could also continue tweaking various power management settings in your OS and BIOS, but I lack deep knowledge about this subject.

adamdiel, 2023-10-11:
Hey great points! I'll have to decomission another project so might take me a few days but I'll try a non deej connection and see if I can get the same behavior!

I figured for point 1 that would be the case but figured it was worth a data point.

So to confirm my understanding - the serial connection not being restored after sleep is a known issue and being investigated however an active serial connection affecting other devices from waking a device would be outside the scope.

Anyways - I'll do some more experiments and see if I can provide any other useful data points!

omriharel, 2023-10-12:
> So to confirm my understanding - the serial connection not being restored after sleep is a known issue and being investigated

Yes, tracked in the duplicate issues I pointed at earlier and will be fixed in the next version of deej (which in general will make the connection mechanism a lot more robust and intuitive than it currently is).

> however an active serial connection affecting other devices from waking a device would be outside the scope

Correct, because my suspicion is that this isn't a problem unique to deej (even though deej is one possible way to cause it, because it maintains an active long-term serial connection).

I'll close this for now but feel free to post more data below later on if you collect it.

Closed 2023-10-12.

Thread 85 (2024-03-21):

Open and close quickly without any error messages

dumaster, 2024-03-21:
Is this behavior normal when the Arduino is not connected to USB? Shouldn't it display an error message stating that it was not possible to connect to the specified port ???

I'm using the latest build !!!

Wouldn't it be interesting when it doesn't find the COM to open a window with the option to reconnect and close ???

Congratulations on the project and thanks for the space to suggest improvements !!!

omriharel, 2024-03-21:
Hi @dumaster, thanks for writing.

deej currently doesn't have a GUI, but you can run its debug version (also available in the releases page) in a command terminal to see the logs there. In addition, there is a Windows notification whenever deej fails to connect - is it possible you have system notifications turned off, or Do Not Disturb, or similar?

Finally, the release version of deej creates a log file for the last run - you should be able to see connection errors there too.

Please let me know if you have any questions. Thanks!

dumaster, 2024-03-23:
Thanks for the quick response, this project of yours is a fantastic idea, I'm here now testing it with a potentiometer just to understand how it works !!!

My notifications are actually silenced, my fault, I opened the notifications side menu and it was there the alert of disconnected COM, a suggestion if you find it interesting would be when it doesn't find the COM it opens a pop-up also warning that it couldn't communicate with the COM configured giving two alternatives of clicks buttons which would be to Exit and Reconnect !!!

I had other doubt ( this was motive of my curiosity and quickly assembled an Arduino UNO with a potentiometer to test ) was if some other software in background or the user changed the volume on the mixer, would the volume remain applied until you moved the slider or if after time a while a it would check the value of the slider comparing it with the computer and detecting a difference, if found difference he adjusted the volume again to the Slider value , and indeed, if the volume was changed outside of the deej, the volume will remain changed until you change the slider for that application that had the volume changed, then a second suggestion would be to have an option in the configuration file where you enable the application on the host from time to time ( perhaps a adjustable time ) to check and compare the volumes and if it finds any difference, it returns the volumes in the mixer to be the same as the sliders !!!!!!

But these are cosmetic suggestions, your project already works very well, I really liked the initiative of this project, it was something that was missing for many users like me who want an easy command close to their hands for the entire Windows volume system, congratulations on the project !!!

Thanks @omriharel

Edward.

omriharel, 2024-03-23:
Hi @dumaster, thanks for the kind words about the project.

I will address both your suggestions:

- There is currently no GUI at all to deej, so it is not possible to bring up a dialog or other type of window. There will eventually be a full GUI, which will of course indicate about any connection issue and offer guidance on how to solve it.
- The behavior you've described is fully intentional. It is both for performance (responding to user pot changes, as opposed to continuously polling the volumes of running apps), and to allow users to change the volume in software if they need to (without having it instantly overridden). I don't have current plans to make it configurable.

Closed 2024-03-23.

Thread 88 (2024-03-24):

Deej with logarithmic Potentiometers

CodingFactoryT, 2024-03-24:
I only have logarithmic slider potentiometers. What can I do?

omriharel, 2024-03-24:
Hi @CodingFactoryT, thanks for writing.

Unfortunately, there isn't much you can _really_ do to make logarithmic pots work perfectly. It's not that they won't be usable, it just won't be completely ideal.

As you might know, a logarithmic taper on pots is the typically suitable one for audio-related applications. But in the case of operating systems like Windows, there is already a linearization of the software volume controls (which is what deej changes) which means that the control needs to be linear.

Since the physical properties of a logarithmic pot define the mathematical function that determines its resistance based on its wiper position, there isn't a great way to reverse them in software. That missing resolution around the sharper parts of the curve just gets lost, so even if you try to come up with a reverse calculation that tries to mimic a linear taper, you'd still be left with a pot that feels less accurate and less linear than an actual linear pot.

But with all that said - it's not necessarily a huge deal. You should still give such a potentiometer a try (maybe on a breadboard, just as a quick prototype), and see how it feels - maybe it'll be good enough for you!

Please let me know if you have other questions. Thanks!

CodingFactoryT, 2024-03-24:
Thanks for your detailed answer! I searched very long for a solution, and I have found one which can map the logarithmic values to linear ones. I created a pull request so that everyone can benefit from it.

omriharel, 2024-03-24:
Hi @CodingFactoryT, I looked at your PR but as I explained in my above answer, it isn't a real solution that allows to make better use out of a logarithmic pot. Feel free to use it for yourself if you believe it helps.

Closed 2024-03-24.

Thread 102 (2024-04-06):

Community/Dimitar schematic is wrong

frankrpeters, 2024-04-06:
The schematic in assets/community-builds/extra is wrong and should not be used. If you wire your device in this way, you will short out your power source if you simultaneously turn up the voulme of any channel to full and mute it. Since this should be caught by the USB shortout protection for devices over USB, I would, however, not expect permanent damage in most cases.

The correct wiring would be to swap the connections of pins 2 and 3 for every switch. This would lead to pull down the potential of the corresponding input instead of leaving it floating when muted, At the same time it would prevent the switch to bridge the "lower half" of the poti.

I would assume that this is what Dimitar intended, however, this is not currently reflected in the schematic.

omriharel, 2024-04-19:
Hi @frankrpeters, thanks for writing and for the report! Unfortunately I don't have a great way to change the sketch files as they were provided by Dimitar as-is, but I'll link to your explanation near those links in a future edit. Thanks again!

frankrpeters, 2024-04-19:
Hi,

if you can wait some time, I'll probably get around to edit the files myself and send you the changed files.

Regards, Frank

Am 19. April 2024 12:50:35 MESZ schrieb Omri Harel ***@***.***>:
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
--
Diese Nachricht wurde von meinem Android-Mobiltelefon mit K-9 Mail gesendet.
--
Diese Nachricht wurde von meinem Android-Mobiltelefon mit K-9 Mail gesendet.

omriharel, 2024-04-19:
Thanks, you can post them here and whoever follows the link will find them here - I'd rather have that documented in this way rather than change the files provided by the original author.

Closed 2024-04-19.

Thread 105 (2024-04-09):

Max slider value is not adjustable

LovroG05, 2024-04-09:
I run this on an esp32, and when i max the sliders, it returns 4095, which gets flagged as a dirty line. This means i can only use 1/4 of my slider.

Can you please add this to the config?
If you want, i can code it and PR

thanks

I3lackRacer, 2024-04-16:
I made a fix on the Arduino's side, if you want I can open a merge request.

tanishqmanuja, 2024-04-19:
https://github.com/tanishqmanuja/deej/commit/282f79d9855b3370c0c501a2806eff579f0538f2

omriharel, 2024-04-19:
Hi there @LovroG05, thanks for writing. There are no current plans to allow a configurable range of values for the serial interface - the expectation is that devices with a 12-bit ADC instead map the values to the 0-1023 range used in the default Arduino sketch. There is [`map()` function](https://www.arduino.cc/reference/en/language/functions/math/map/) in Arduino to allow you to easily do that.

Putting this as a config option will ultimately result in users attempting to tweak it to try and solve issues that originate in incorrect wiring, faulty pots, etc. - and thus will also make it more difficult to help them with troubleshooting.

Closed 2024-04-19.

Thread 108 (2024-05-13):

Pause/Play command

Adib-C, 2024-05-13:
Is it possible to send a Play/Pause command to deej when pressing a button connected to the Arduino?

Adib-C, 2024-06-01:
I understand, but it would be nice if this feature gets added to deej though 😊

neroes, 2024-06-15:
i second this, although it would like expand it to general media buttons such as end call, stop & skip song, and mute for the different sliders

TheScabbage, 2024-06-16:
The main repo is mostly abandoned, but there are many forks of Deej with extensive changes:
https://github.com/Miodec/deej

This one adds the keybd_event library for configurable button mapping.

Adib-C, 2024-06-17:
Aah I see, I didn't know this is mostly abandoned , thanks for letting me know, and I will check out other forks.

Lefuneste83, 2024-06-22:
> Aah I see, I didn't know this is mostly abandoned , thanks for letting me know, and I will check out other forks.

Hi there.

I was facing the same issue before I decided to Fork this amazing (but abandoned) project myself as plenty other did. It is unfortunate that we cannot consolidate features into one single repo which should be the goal of github instead of having hundreds of tiny mods all over the place.

It is indeed very possible to have touch buttons, hardwired, capacitive or anything you want. You can checkout the code on my repo I have implemented such a possibility in the Go portion of the project, along with various interesting mods I have gathered around. I am working on Linux so not sure yet if the code properly deploys on Windows. There might be some sticky bits with one architecture or another such as key mappings different in these systems for some functions, but with proper testing it should all be solvable quite easily.

Keep in mind that Arduino while a great tool for starters and also because of its decent ADC chip, seems quite a bit outdated compared to current possibilities offered by various MCU devboards. Arduino is not much simpler than other MCU as long as you have a good grasp on C++.

Keep in mind that while my code is in a working state (I have it running for several weeks now), it needs some cleanup as I used to be totally new to Go Language apart from compiling Loki Docker driver for a Raspberry Pi once in a while. Also you will have to modify your Arduino code but it is quite simple. Let me know if you need some tips.

The architecture of this project code is dual. One part is in Go and purely deals with the server side and does all the interfacing with the sound backend. It is by far the most remarkable piece of software of the project. The other part is the client side which is by default a simple Arduino script. There are millions of possibilities with such an architecture. Some people hardwired their switch to pulldown the fader (ghetto style),, but you can go as far as you like. At the moment I have implemented software defined fader curve and it allows you to tweak the response of any fader you have in your build.

I intend to refactor the server code for good once I have my hardware complete with all the features I wantto implement. I will update my repo with all information soon.

omriharel, 2024-06-23:
Hi there @Adib-C, @neroes, @TheScabbage and @Lefuneste83 - thank you for writing.

First and foremost please let me address the primary subject of this issue - media controls (and more broadly, key bindings). They're something I consider to be out-of-scope for the vanilla version of deej at this point in time. I might opt to add them in a future release, but until then - as mentioned above there are forks with support for this functionality and I encourage you to use those forks instead.

I'd like to also take the time to address the above comments regarding the project's state and to clarify - deej is _not_ an abandoned project. The notion that it's abandoned is honestly quite preposterous to me. A project not receiving issue comments from its maintainer for a few weeks doesn't make it abandoned - nor that it hadn't had pushed commits in an admittedly long time, and thirdly nor that it has a non-standard [contribution policy](https://github.com/omriharel/deej/blob/master/docs/CONTRIBUTING.md).

Let's talk about that third point briefly - specifically to address this comment:

> It is unfortunate that we cannot consolidate features into one single repo which should be the goal of github

Well, yes but not really. GitHub is a collaborative platform, but on the other hand - open-source can mean a wide range of things and its most basic definition is "the source code is freely available". It doesn't necessarily imply open collaboration. The reasons I outlined in my above document (for not wanting to receive direct contributions to this main repository) have not changed since that document was written.

The notion of "consolidating features into a single repo" sounds like a wonderful thing, but the nature of how customizable and how personalized this project can be simply means that there is no sane way to support and maintain the large amount of features thought up by the thousands of users within the deej community - all in one place. I see the existence of hundreds of different forks which accomplish different features - some with broad appeal and some extremely niche - as a good thing, in spite of their discoverability leaving a lot to be desired.

Finally, I'd like to point out a couple of other things that should (in my opinion) signal that deej is nowhere near being at an abandoned state:

- it has an active Discord community with over 6000 members, including an extensive build showcase channel which sees new builds by members posted almost daily, as well as including several authors of prominent forks who often answer community-posted questions regarding functionality in their forks
- there is behind-the-scenes work by me on the next deej release, which includes a massive overhaul to the connection mechanism aimed at improving robustness and stability as well as a decent amount of bug fixes (there is no designated ETA for this version's release - I work on it alone and at my own discretion, as mentioned in the document linked above)

If you'd like to continue the discussion on the project's state, I encourage you to DM me through the project's Discord server; I realize this response is very defensive, it's just difficult for me to see the "abandoned" term being thrown around in this manner - deej is extremely dear to me and so it was important for me to take the time and clear up my own point-of-view. If you took the time to read through all of this - **thank you**.

Closed 2024-06-23.

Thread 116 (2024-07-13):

Ready to use purchasable controllers?

Eiion, 2024-07-13:
Are there cheap/very affordable devices that can be purchased and are widely available which are compatible with deej?

omriharel, 2024-07-13:
Hi there @Eiion - deej is a non-commercial project intended for a DIY audience, and as such I won't be pointing you towards anything of this sort. That being said I don't control what others choose to do around the project, so inevitably some people are going to be selling hardware. However I ask that you don't discuss it on this public platform, as I prefer not to promote this type of thing. Please also be aware that our community Discord server would not be an appropriate space for it either. Thank you.

Eiion, 2024-07-14:
Not even the discord server, where you could create a channel to allow people discussing commercial products that are compatible - with the role to not post store links? Where else should we discuss it, a place where users of the software meet? While I get your point this seems highly limiting to your own project as not everyone has the needed tools to assemble the hardware as intended or even print a case. If there's affordable compatible devices you should give that a space the discuss them. I hope you'll reconsider your current point of view on that.

omriharel, 2024-07-14:
Hi @Eiion, while I understand the possible frustration around this decision I feel that it is reasonable for me to set the spirit and intended direction for a project in this manner. I'm not prohibiting the very notion of ready made devices, I'm simply asking users that are interested in them to do their research independently.

It's worth mentioning that you do not need expensive soldering equipment or a 3D printer to make a functional and nice looking deej build either - you're welcome to look in our community showcase for some creative examples of builds made fully using a breadboard or out of. cardboard. I made my first iteration of this project using a shoebox.

I hope this inspires you to look in the DIY direction, but if you wish to still go with readily made hardware then please seek it independently. Thank you.

Closed 2024-07-13.

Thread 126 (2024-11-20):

deej doesn't work after windows update

Frstikowl, 2024-11-20:
deej stopped working. Until one moment everything was just fine. Now, when I launch the program, it does not see the sliders, although everything is configured correctly, restarting also does not help.
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

Frstikowl, 2024-11-20:
I rolled back the operating system to the last restore point that was automatically created before the update. Everything worked, apparently the new patch "wch.cn-Ports-3.9.2024.9" is to blame. I'm using Windows 11.
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

24pmabb8, 2024-11-20:
It's a driver issue.  Was able to resolve by reinstalling the older driver (roll back was not available for me).  Device Manager > Ports (COM & LPT).  Find the COM port associated with the Arduino.

Recent Win Update updated the CH340 driver to newer version dated this year.  You can do a web search for an older one.  I found one dated 2019.  Deej working again after driver update.

Frstikowl, 2024-11-20:
Thank you very much, now everything works.

richardjharding, 2024-11-28:
Same here on win11 - open device manager and click the "rollback driver" to previous version fixed it for me

Closed 2024-11-20.

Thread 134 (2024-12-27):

Volume not changing for games Win 11

JedaCheese, 2024-12-27:
I am having issues with changing the volume for any games that are running. Discord, Chrome and Main volume adjust perfectly. I never had this issue on my Windows 10 PC (I've just built a new PC and it has Win 11)

Config file is as follows:
# process names are case-insensitive
# you can use 'master' to indicate the master channel, or a list of process names to create a group
# you can use 'mic' to control your mic input level (uses the default recording device)
# you can use 'deej.unmapped' to control all apps that aren't bound to any slider (this ignores master, system, mic and device-targeting sessions) (experimental)
# windows only - you can use 'deej.current' to control the currently active app (whether full-screen or not) (experimental)
# windows only - you can use a device's full name, i.e. "Speakers (Realtek High Definition Audio)", to bind it. this works for both output and input devices
# windows only - you can use 'system' to control the "system sounds" volume
# important: slider indexes start at 0, regardless of which analog pins you're using!
slider_mapping:
  0: master
  1:
    - bg3.exe
    - bg3_dx11.exe
    - factorio.exe
    - Medieval_Dynasty.exe
    - Ranch_Simulator.exe
    - WalkingSim.exe
  2: discord.exe
  3: chrome.exe
  4: spotify.exe

# set this to true if you want the controls inverted (i.e. top is 0%, bottom is 100%)
invert_sliders: false

# settings for connecting to the arduino board
com_port: COM3
baud_rate: 9600

# adjust the amount of signal noise reduction depending on your hardware quality
# supported values are "low" (excellent hardware), "default" (regular hardware) or "high" (bad, noisy hardware)
noise_reduction: default

michaelwschultz, 2025-03-24:
Give this build a shot #146

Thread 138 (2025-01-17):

deej no longer opens up

Boerny41, 2025-01-17:
When trying to start deej.exe nothing happens. This is the error log:
It worked before.
```
2025-01-17 18:53:01.488	info	main                       	Version info	{"gitCommit": "7567f83", "versionTag": "v0.9.10", "buildType": "release"}
2025-01-17 18:53:01.529	info	deej.config                	Loaded config successfully
2025-01-17 18:53:01.529	info	deej.config                	Config values	{"sliderMapping": "<5 sliders mapped to 5 targets>", "connectionInfo": {"COMPort":"COM8","BaudRate":9600}, "invertSliders": false}
2025-01-17 18:53:01.552	warn	deej.session_finder        	Failed to enumerate and add process sessions for device	{"deviceIdx": 0, "error": "error 2290679816 (FormatMessage failed with: The system cannot find message text for message number 0x%1 in the message file for %2.)"}
2025-01-17 18:53:01.553	warn	deej.session_finder        	Failed to enumerate device sessions	{"error": "enumerate and add device 0 process sessions: error 2290679816 (FormatMessage failed with: The system cannot find message text for message number 0x%1 in the message file for %2.)"}
2025-01-17 18:53:01.553	warn	deej.sessions              	Failed to get sessions from session finder	{"error": "enumerate device sessions: enumerate and add device 0 process sessions: error 2290679816 (FormatMessage failed with: The system cannot find message text for message number 0x%1 in the message file for %2.)"}
2025-01-17 18:53:01.553	warn	deej.sessions              	Failed to get all sessions during session map initialization	{"error": "get sessions from SessionFinder: enumerate device sessions: enumerate and add device 0 process sessions: error 2290679816 (FormatMessage failed with: The system cannot find message text for message number 0x%1 in the message file for %2.)"}
2025-01-17 18:53:01.553	error	deej                       	Failed to initialize session map	{"error": "get all sessions during init: get sessions from SessionFinder: enumerate device sessions: enumerate and add device 0 process sessions: error 2290679816 (FormatMessage failed with: The system cannot find message text for message number 0x%1 in the message file for %2.)"}
github.com/omriharel/deej.(*Deej).Initialize
	D:/Projects/go/src/github.com/omriharel/deej/deej.go:97
main.main
	D:/Projects/go/src/github.com/omriharel/deej/cmd/main.go:63
runtime.main
	c:/go/src/runtime/proc.go:203
2025-01-17 18:53:01.553	fatal	main                       	Failed to initialize deej	{"error": "init session map: get all sessions during init: get sessions from SessionFinder: enumerate device sessions: enumerate and add device 0 process sessions: error 2290679816 (FormatMessage failed with: The system cannot find message text for message number 0x%1 in the message file for %2.)"}
main.main
	D:/Projects/go/src/github.com/omriharel/deej/cmd/main.go:64
runtime.main
	c:/go/src/runtime/proc.go:203

```

Boerny41, 2025-01-17:
Found the answer in an unrelated thread:

I updated my GPU drivers yesterday, and it re-enabled my monitors as audio devices. Disabling them again allows deej to start.

Closed 2025-01-17.

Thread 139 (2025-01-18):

Sound only goes from 0% to 85%

brunoafg, 2025-01-18:
This is not a problem from the code but from the hardware itself.

I have a workaround so other people can bypass the issue.

The volume dont reach 100% in computer or if inverted, goes from 100% to like 15%.

Somehow, the output on the console only reach 850. For what i understand, this can be caused by "noise", quality of wires/pot's or even if the arduino cant output exactly 5v (like 4.8v).

I've changed the updateSliderValues() with a map function, it scales the real output value to value that we want. This must be analized case by case and conditions can be needed if not all the outputs give the same real output (Ex. Out1 = 850, Out2 = 1000, Out3 = 500, etc).

void updateSliderValues() {
    for (int i = 0; i < NUM_SLIDERS; i++) {
        analogSliderValues[i] = analogRead(analogInputs[i]);
        // Map the value to the range 0-1000 based on the observed max output
        //map([arduino_input], [real_output_min_value], [real_output_max_value], [min_wanted_virtual_value], [max_wanted_virtual_value])
        analogSliderValues[i] = map(analogSliderValues[i], 0, 850, 0, 1023);
    }
}

Hope that this helps someone

ninjakilpirate, 2025-03-29:
I had this problem as well when I was running them in serial.  I had my inputs power and ground connections daily chained which I think reduced the overall voltage reading by the analog pin.  I changed to wire each in individually, braided the power wires together, and connected and I started getting the correct values.

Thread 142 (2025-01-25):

Deej preventing computer from sleeping, could not get any solutions from google to work

BolSadguy, 2025-01-25:
So sorry to be making another post about this issue but I've tried disabling usb wake up in my device manager (the button to disable it just doesnt exist on my end for some reason) and I've also tried adjusting the arduino code based on [#52 ](https://github.com/omriharel/deej/issues/52#issuecomment-1079436904) and I haven't been able to get my computer to remain in sleep while deej is running. Admittedly I don't know too much about programming arduinos so I'm not sure if I even inserted the new code in the correct way or into the correct spots. Here's what I have, please let me know what I'm doing wrong. Thanks in advance

`const int NUM_SLIDERS = 9;
const int analogInputs[NUM_SLIDERS] = {A6, A7, A8, A9, A3, A2, A1, A0, A10};
String oldValues;

int analogSliderValues[NUM_SLIDERS];
int oldAnalogSliderValues[NUM_SLIDERS];
void setup() {
  for (int i = 0; i < NUM_SLIDERS; i++) {
    pinMode(analogInputs[i], INPUT);
    oldAnalogSliderValues[i] = analogSliderValues[i] = analogRead(analogInputs[i]);
    if(abs(oldAnalogSliderValues[i] - analogSliderValues[i]) <= 2) analogSliderValues[i] = oldAnalogSliderValues[i];
    oldAnalogSliderValues[i] = analogSliderValues[i];
  }

  Serial.begin(9600);
}

void loop() {
  updateSliderValues();
  sendSliderValues(); // Actually send data (all the time)
  // printSliderValues(); // For debug
  delay(10);
}

void updateSliderValues() {
  for (int i = 0; i < NUM_SLIDERS; i++) {
     analogSliderValues[i] = analogRead(analogInputs[i]);
  }
}

void sendSliderValues() {
  String builtString = String("");

  for (int i = 0; i < NUM_SLIDERS; i++) {
    builtString += String((int)analogSliderValues[i]);

    if (i < NUM_SLIDERS - 1) {
      builtString += String("|");
    }
  }

  if(oldValues != builtString) Serial.println(builtString); oldValues = builtString;
}

void printSliderValues() {
  for (int i = 0; i < NUM_SLIDERS; i++) {
    String printedString = String("Slider #") + String(i + 1) + String(": ") + String(analogSliderValues[i]) + String(" mV");
    Serial.write(printedString.c_str());

    if (i < NUM_SLIDERS - 1) {
      Serial.write(" | ");
    } else {
      Serial.write("\n");
    }
  }
}`

natsnok, 2025-01-25:
Is it possible that the potentiometers being used fluctuate between values? Check with the debug function to see if there's a slight change in volume even when the potentiometers are not being used. You could implement a function in the code that only sends slider values when the change is significant enough (when the potentiometer is actually being adjusted).

However, please note that for the Deej program to function correctly, values must be sent continuously. Otherwise, it won't respond at all. In other words, if a potentiometer is not being used, always send a fixed value. Only update this fixed value when the change is significant enough to ensure that you are actually adjusting the potentiometer.

BolSadguy, 2025-01-25:
``

> Is it possible that the potentiometers being used fluctuate between values? [...] You could implement a function in the code that only sends slider values when the change is significant enough (when the potentiometer is actually being adjusted).
>
> [...] In other words, if a potentiometer is not being used, always send a fixed value. Only update this fixed value when the change is significant enough to ensure that you are actually adjusting the potentiometer.

I was under the impression that that's what the code adjustments in #52 were accomplishing.

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

But again, I'm not sure if I added the code to the correct spots in the code I posted earlier.

michaelwschultz, 2025-03-24:
Give this build a shot #146. Let me know if it works for you.

BolSadguy, 2025-03-24:
> Give this build a shot [#146](https://github.com/omriharel/deej/issues/146). Let me know if it works for you.

Thanks for getting back to me. Unfortunately I tried the new deej.exe but the same issues occured and theres now a considerable delay between moving a slider and the volume actually changing.

Not sure if it makes a difference or not but I'm running 9 pots on my deej.

Please let me know if there are any additional steps to try.

Thanks again

michaelwschultz, 2025-03-25:
@BolSadguy what version of windows are you running? Also, would you mind uploading your logs file? It should be in the same folder as where you ran the latest deej build. I'll take a look in a few hours. ☺️

michaelwschultz, 2025-03-28:
@BolSadguy another thing that would be helpful is running `powercfg /requests` after opening your Powershell as administrator. This should tell you which applications or hardware are preventing your machine from sleeping currently.

Make sure you have your Deej plugged in and the new build running.

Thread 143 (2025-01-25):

Driver issues - 3.5.2019.1

natsnok, 2025-01-25:
My Deej is unresponsive.
It seems to be an issue with the driver being used. When I use the driver version 3.5.2019.1, it works fine until I restart the system. Only after switching to a current driver version and then back to version 3.5.2019.1 does it work again.

Has anyone experienced similar issues or have any solutions?

ki2chio, 2025-01-25:
Try to install this fix for the driver, it helped me https://www.visualmicro.com/page/CH340-Driver-Fix-Installation.aspx

natsnok, 2025-01-26:
> Try to install this fix for the driver, it helped me https://www.visualmicro.com/page/CH340-Driver-Fix-Installation.aspx
This is the driver I am using.

I have figured out exactly where deej stops responding.
When I upload code for another Arduino project to a different COM port via VSCode -> PlatformIO, it seems to somehow affect the driver or the settings.
Because only after using VSCode -> PlatformIO and restarting the system, deej becomes unresponsive.

natsnok, 2025-01-27:
Problem solved after months of pain :D

Bypassing driver signature: Make sure Windows doesn’t replace the 30.01.2019 driver. You can disable automatic driver installation by following these steps:

    Open Control Panel → System → Advanced System Settings.
    Under the Hardware tab, go to Device Installation Settings and select: “No, let me choose what to do.”

Closed 2025-01-27.

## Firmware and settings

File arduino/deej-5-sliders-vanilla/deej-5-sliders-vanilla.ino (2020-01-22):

const int NUM_SLIDERS = 5;
const int analogInputs[NUM_SLIDERS] = {A0, A1, A2, A3, A4};

int analogSliderValues[NUM_SLIDERS];

void setup() { 
  for (int i = 0; i < NUM_SLIDERS; i++) {
    pinMode(analogInputs[i], INPUT);
  }

  Serial.begin(9600);
}

void loop() {
  updateSliderValues();
  sendSliderValues(); // Actually send data (all the time)
  // printSliderValues(); // For debug
  delay(10);
}

void updateSliderValues() {
  for (int i = 0; i < NUM_SLIDERS; i++) {
     analogSliderValues[i] = analogRead(analogInputs[i]);
  }
}

void sendSliderValues() {
  String builtString = String("");

  for (int i = 0; i < NUM_SLIDERS; i++) {
    builtString += String((int)analogSliderValues[i]);

    if (i < NUM_SLIDERS - 1) {
      builtString += String("|");
    }
  }
  
  Serial.println(builtString);
}

void printSliderValues() {
  for (int i = 0; i < NUM_SLIDERS; i++) {
    String printedString = String("Slider #") + String(i + 1) + String(": ") + String(analogSliderValues[i]) + String(" mV");
    Serial.write(printedString.c_str());

    if (i < NUM_SLIDERS - 1) {
      Serial.write(" | ");
    } else {
      Serial.write("\n");
    }
  }
}

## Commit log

2020-01-23 add hardware schematic
2020-03-05 add proper parts list to readme, add link to arduino blog feature in community feature
2020-05-03 move arduino sketch to own directory and namespace for future variants
2020-05-05 crash fix for refreshing processes after switching audio device
2020-05-05 correctly handle interrupts
2020-05-12 fix occasional access violation crash when switching audio devices
2020-05-23 add dimitar build to community showcase
    [dimitar-schematic.sch]
2020-06-16 fix bug where deej cannot start if no input device is found
2020-07-28 add multi-device support on windows
2020-07-28 document multi-device support on windows
2020-08-31 add support for advanced target resolution; add support for current (windows) and unmapped sessions; fix bug preventing control of some UWP apps
2020-08-31 acquire current foreground window more intelligently, accomodating all kinds of container-like apps (not just UWP)
2020-08-31 remove spammy log message of current app that remained from testing
2020-08-31 document current and unmapped options; update release notes template
2021-03-18 minor readme changes, phase out experimental status on current/unmapped
2021-04-07 update landing page picture with own 3d-printed version
